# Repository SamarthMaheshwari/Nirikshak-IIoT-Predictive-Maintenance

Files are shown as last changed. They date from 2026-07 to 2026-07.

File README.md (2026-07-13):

# Nirikshak: Industrial IoT Predictive Maintenance System

<p align="center">
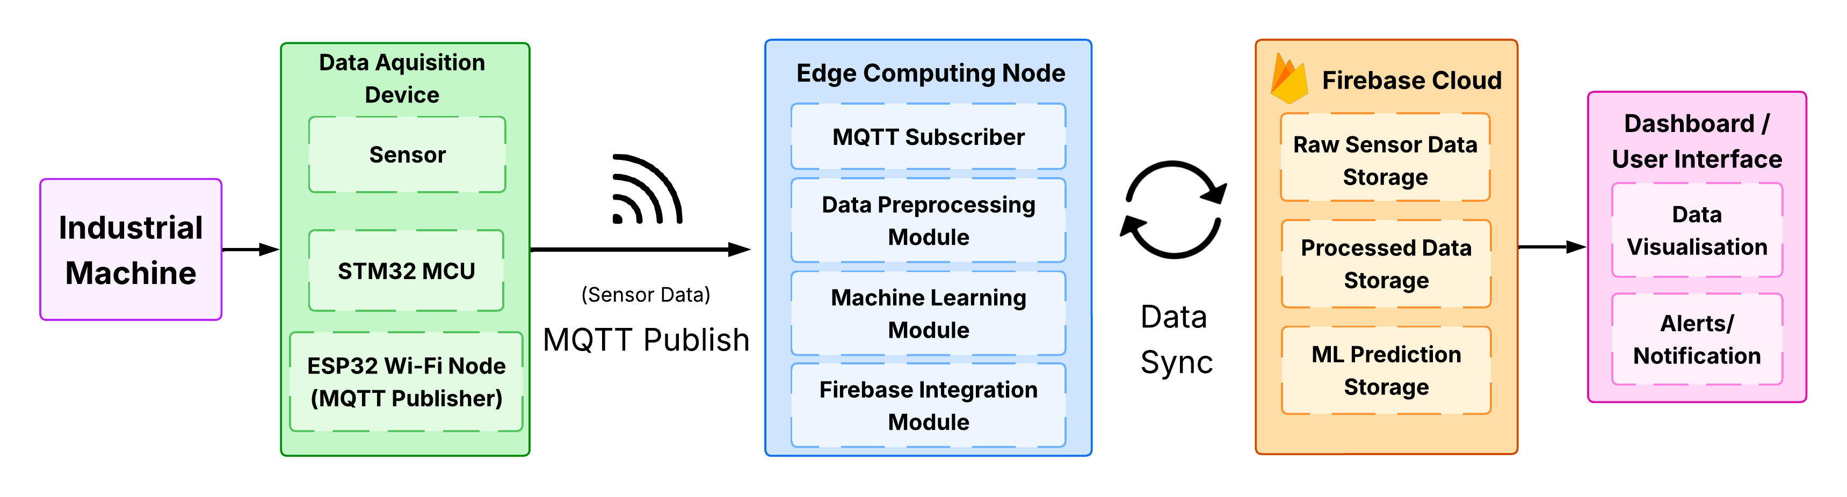
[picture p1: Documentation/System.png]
Nirikshak System
  
</p>

<p align="center">

An Industrial Internet of Things (IIoT) based Predictive Maintenance System for real-time monitoring of industrial motors using a custom STM32 Data Acquisition (DAQ) device, ESP32 wireless communication, and a web-based monitoring dashboard.

</p>

---

## Overview

Nirikshak is a low-cost Industrial IoT (IIoT) solution developed to continuously monitor the health of industrial motors.

The system collects data from multiple sensors using a custom-designed STM32-based DAQ device and wirelessly transmits it through an ESP32 module. The incoming telemetry is processed by a Python backend and visualized on a real-time dashboard, enabling continuous monitoring of machine operating conditions.

The project demonstrates the complete workflow of an embedded monitoring system—from hardware design and firmware development to wireless communication and web-based visualization.

---

# Features

- Real-time industrial motor monitoring
- Custom STM32-based Data Acquisition (DAQ) Device
- ESP32 wireless communication
- Multi-sensor data acquisition
- MQTT/Firebase based data transfer
- Live dashboard visualization
- Custom PCB designed in EasyEDA
- Custom 3D enclosure
- Modular firmware architecture
- Automatic dashboard fallback using simulated telemetry
- Easy-to-expand system architecture

---

# System Architecture

```
Industrial Motor
        │
        ▼
Sensors
│
├── MPU6050 (Vibration)
├── DS18B20 (Temperature)
├── ZMPT101B (Voltage)
├── SCT-013 (Current)
└── Inductive Proximity Sensor (RPM)
        │
        ▼
STM32 BlackPill
(Data Acquisition)
        │
UART
        │
        ▼
ESP32 DevKit V1
        │
Wi-Fi
        │
Firebase / MQTT
        │
Python Backend
        │
Real-Time Dashboard
```

---

# Hardware

## Microcontrollers

- STM32 BlackPill (STM32F411)
- ESP32 DevKit V1

## Sensors

- MPU6050
- DS18B20
- ZMPT101B Voltage Sensor
- SCT-013 Current Sensor
- Inductive Proximity Sensor

---

# Software Stack

| Software | Purpose |
|---|---|
| Arduino IDE | Firmware Development |
| Python | Backend & Dashboard |
| Flask | Web Dashboard |
| Socket.IO | Real-time Dashboard Updates |
| MQTT | Communication |
| Firebase | Cloud Data Storage |
| EasyEDA | PCB Design |
| Git & GitHub | Version Control |

---

# Repository Structure

```
Nirikshak
│
├── Firmware
│   ├── STM32
│   └── ESP32
│
├── Hardware
│   ├── PCB
│   └── 3D_Enclosure
│
├── Dashboard
│   ├── Backend
│   ├── Images
│   └── README.md
│
├── Documentation
│
├── Images
│
├── README.md
└── LICENSE
```

---

# Firmware

The firmware consists of two parts:

### STM32 Firmware

Responsible for:

- Sensor interfacing
- Data acquisition
- Signal processing
- UART communication

### ESP32 Firmware

Responsible for:

- Receiving data from STM32
- Wireless communication
- Sending telemetry to Firebase/MQTT

---

# Dashboard

The dashboard provides real-time visualization of sensor data including:

- Temperature
- Voltage
- Current
- RPM
- Vibration
- Machine Health Status
- Historical Readings
- System Statistics

The complete dashboard source code and setup instructions are available in:

```
Dashboard/README.md
```

---

# PCB

The custom DAQ PCB was designed using EasyEDA.

Included files:

- EasyEDA Project
- PCB Layout
- Schematic
- PCB Images
- 3D PCB View

---

# 3D Enclosure

The repository includes the custom enclosure designed for the DAQ device.

Contents include:

- STEP Files
- Preview Images

---

# Running the Project

## Firmware

Upload:

- STM32 firmware to the STM32 BlackPill
- ESP32 firmware to the ESP32 DevKit

---

## Dashboard

Navigate to the backend directory:

```bash
cd Dashboard/Backend
```

Install dependencies:

```bash
pip install -r requirements.txt
```

Run the dashboard:

```bash
python app.py
```

Open your browser and visit:

```
http://localhost:5000
```

For detailed dashboard instructions, see:

```
Dashboard/README.md
```

---

# Project Gallery

Add screenshots inside:

```
Images/
```

Example:

```
Images/
├── System.png
├── PCB.png
├── Dashboard.png
├── Enclosure.png
└── Hardware.jpg
```

---

# Future Improvements

- Industrial communication protocols (Modbus, CAN)
- OTA firmware updates
- Multi-machine monitoring
- Cloud deployment
- Mobile dashboard
- Edge-based predictive analytics

---

# Author

**Samarth Maheshwari**

Electronics & Telecommunication Engineering

**Areas of Interest**

- Embedded Systems
- Industrial IoT
- Firmware Development
- PCB Design

**GitHub**

https://github.com/SamarthMaheshwari

**LinkedIn**

https://www.linkedin.com/in/samarth-maheshwari-709670259

---
# Contributors

This project was developed as a collaborative Final Year Engineering Project.

- **Samarth Maheshwari**
- **Shriraj Dongare**
- **Anisha Pansare**

---

# Acknowledgements

This project was developed as a collaborative Final Year Engineering Project.

I would like to sincerely thank my teammates, **Shriraj Dongare** and **Anisha Pansare**, for their collaboration, dedication, and continuous support throughout the development of this project. Their teamwork and contributions were instrumental in successfully completing the project.

---

# License

This project is licensed under the MIT License.

See the LICENSE file for more information.

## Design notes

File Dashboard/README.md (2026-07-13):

# Dashboard

The Dashboard provides a real-time web interface for monitoring sensor data collected by the **Nirikshak Industrial IoT Predictive Maintenance System**.

It receives live sensor data through the backend, processes incoming telemetry, and displays the current machine status, historical data, and system statistics in an interactive web interface.

---

# Folder Structure

```
Dashboard/
│
├── Backend/
│   ├── app.py
│   ├── mqtt_subscriber.py
│   ├── config.py
│   ├── firebase_setup.py
│   ├── firebase_publisher.py
│   ├── pipeline.py
│   ├── requirements.txt
│   ├── templates/
│   ├── static/
│   ├── utils/
│   ├── ml/
│   ├── Firebase/
│   ├── Simulation/
│   └── Documentation/
│
├── Images/
└── README.md
```

---

# Features

- Real-time sensor monitoring
- Live dashboard updates using Socket.IO
- Historical data visualization
- Machine health monitoring
- Automatic fallback to simulated sensor data when no live data is available
- Responsive web interface

---

# Prerequisites

- Python 3.10 or later
- Internet connection (if using Firebase)
- Git (optional)

---

# Installation

Open a terminal inside the **Backend** folder.

Install the required Python packages:

```bash
pip install -r requirements.txt
```

---

# Running the Dashboard

Navigate to the Backend folder:

```bash
cd Dashboard/Backend
```

Run the application:

```bash
python app.py
```

If everything starts correctly, you should see a message similar to:

```
Nirikshak Dashboard -> http://localhost:5000
```

Open the displayed URL in your web browser.

Example:

```
http://localhost:5000
```

---

# Data Source

The dashboard automatically retrieves sensor data using the configured backend services.

Depending on the project configuration, data may come from:

- Firebase Realtime Database
- MQTT Subscriber
- Local simulator (automatic fallback)

If no live sensor data is available, the application generates simulated telemetry so the dashboard remains functional for demonstration purposes.

---

# Firebase Configuration

If you want to use your own Firebase project:

1. Create a Firebase Realtime Database.
2. Update the Firebase configuration in:

```
Backend/config.py
```

3. Replace the database URL with your own Firebase URL.

The Firebase folder also contains:

- Firebase security rules
- Firebase setup documentation

---

# Dashboard Pages

| Route | Description |
|---|---|
| `/` | Home page |
| `/home` | Home page |
| `/dashboard` | Real-time dashboard |
| `/api/latest` | Latest sensor data |
| `/api/history` | Historical data |
| `/api/stats` | System statistics |

---

# Notes

- `app.py` is the main entry point of the dashboard.
- The MQTT subscriber is started automatically in the background when the application launches.
- No additional terminal or manual execution of the subscriber is required.

---

# Screenshots

Add dashboard screenshots inside the `Images` folder and reference them here.

Example:

```
Images/
├── dashboard_home.png
├── dashboard_live.png
└── dashboard_statistics.png
```

---

# Troubleshooting

### Missing Python packages

Install all dependencies again:

```bash
pip install -r requirements.txt
```

---

### Dashboard does not open

Verify that:

- Python is installed correctly.
- All required packages are installed.
- The configured port is available.

---

### No live sensor data

The dashboard automatically switches to simulated sensor data when no live telemetry is detected, allowing the interface to remain operational for testing and demonstration.

---

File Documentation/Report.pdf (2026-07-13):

SAVITRIBAI PHULE PUNE UNIVERSITY

A PROJECT STAGE II REPORT
ON

## Nirikshak: An Industrial IoT & Predictive Maintenance Framework

SUBMITTED TOWARDS THE
PARTIAL FULFILLMENT OF THE REQUIREMENTS OF

### BACHELOR OF ENGINEERING

BY
Shriraj Dongare | Exam No: B401220134
Samarth Maheshwari | Exam No: B401220152
Anisha Pansare | Exam No: B401220159

### Under The Guidance of

Dr. Rupali Kawade

### DEPARTMENT OF ELECTRONICS AND TELECOMMUNICATION ENGINEERING

### Pimpri Chinchwad College of Engineering And Research Ravet

A.Y. 2025–2026

PCCOER, Department of E&TC Engineering 2025-26 | 1

### Pimpri Chinchwad College Of Engineering And Research DEPARTMENT OF ELECTRONICS AND TELECOMMUNICATION ENGINEERING

## CERTIFICATE

This is to certify that the Project Entitled

### Nirikshak: An Industrial IoT & Predictive Maintenance Framework

Submitted by

Shriraj Dongare | Exam No: B401220134
Samarth Maheshwari | Exam No: B401220152
Anisha Pansare | Exam No: B401220159

is a bonafide work carried out by Students under the supervision of Dr. Rupali Kawade and it is submitted towards the partial fulfillment of the requirement of Bachelor of Engineering (Electronics & Telecommunication Engineering) Project.

Dr. Rupali Kawade | Dr. K.M. Napte
Internal Guide | H.O.D
Dept. of E&TC Engg. | Dept. of E&TC Engg.
Dr. D.N. Dhake | Dr. H.U. Tiwari
Project Co-ordinator | Principal

EXTERNAL EXAMINER SIGNATURE

PCCOER, Department of E&TC Engineering 2025-26 | 2

Acknowledgement

It gives us great pleasure in presenting the Project Phase-II Report on “Nirikshak: An Industrial IOT & predictive Maintenance Framework”.

We would like to take this opportunity to thank our internal guide Dr. Rupali Kawade for giving us all the help and guidance needed. We are really grateful for the kind support and valuable suggestions provided throughout the project work. We would also like to thank our Project Coordinator Dr. D. N. Dhake for guidance and support.

We are also grateful to Dr. K. M. Napte, Head of the Department of Electronics and Telecommunication Engineering, PCCOER, Ravet, for indispensable support and valuable suggestions.

We are heartily thankful to Dr. H. U. Tiwari, Principal, PCCOER, Ravet, for providing all the support, guidance, research environment and constant motivation to improve our research profile

Shriraj Dongare
Samarth Maheshwari
Anisha Pansare
(B.E. E&TC Engineering)
Department of E&TC Engineering, PCCOER Ravet, 2025-26 | I

### Abstract

Predictive maintenance is an essential technology in Industry 4.0 for increasing equipment reliability, reducing unplanned downtime and minimizing maintenance costs. Conventional maintenance methods are not based on continuous condition monitoring and often lead to unnecessary maintenance or unexpected equipment failure. To tackle these challenges, this project proposes Nirikshak: An Industrial IoT & Predictive Maintenance Framework which provides a low cost and scalable solution for real-time machine health monitoring and intelligent fault prediction. The proposed framework uses a Data Acquisition (DAQ) device based on the STM32F103 integrated with temperature, vibration, RPM, voltage and current sensors to monitor continuously machine operating conditions. The collected sensor data is sent to an edge computing system via an ESP32 Wi-Fi module using the MQTT communication protocol. A Python-centric processing layer is employed for data preprocessing, feature extraction, anomaly detection, fault classification and Remaining Useful Life (RUL) estimation.
Machine learning techniques are used to provide predictive maintenance intelligence. We used Isolation Forest for the anomaly detection to detect abnormal machine behavior, Random Forest Classifier for the fault classification and Random Forest Regressor for Remaining Useful Life prediction . The processed sensor data and prediction results are synchronized with Firebase Realtime Database and visualized through a web-based dashboard that provides real time monitoring, machine health status, alerts, and historical trend analysis.
The developed framework was tested with machine condition data obtained under different operating conditions. Experimental results show effective anomaly detection, accurate fault classification, reliable RUL estimation, low communication latency and real-time responsiveness. The total hardware implementation cost is around Rs.8,500 which makes the system affordable and useful for small and medium scale industries. The proposed framework offers a feasible, scalable, and Industry 4.0-enabled solution for intelligent predictive maintenance applications.
Department of E&TC Engineering, PCCOER Ravet, 2025-26 | II

# INDEX

1 Introduction | 1
2 Literature Survey | 6
3 Methodology | 12
4 Design & Implementation of Proposed System | 15

5 Software Implementation | 31
6 Testing & Troubleshooting | 40
7 Advantages & Applications | 48
8 Conclusion & Future Scope | 51
9 References | 54
Annexure A Plagiarism Report | 56
Annexure B Copyright | 60
Annexure C Review Paper | 71
Annexure D Research Paper | 81
Department of E&TC Engineering, PCCOER Ravet, 2025-26 | IV

Annexure E Project Competition Participation | 91
Department of E&TC Engineering, PCCOER Ravet, 2025-26 | V

# List of Figures

3.1 Block Diagram | 13

4.1 System Architecture of Nirikshak Predictive Maintenance Framework 16
4.2 Flowchart of Nirikshak Predictive Maintenance Framework | 22
4.3 STM32F103 Development Board | 24
4.4 MPU6050 Vibration Sensor | 24
4.5 ESP32 Development Board | 25
4.6 DS18B20 Temperature Sensor | 25
4.7 Inductive Proximity Sensor (RPM Sensor) | 26
4.8 Voltage Sensor Module | 26
4.9 SCT-013 Current Sensor | 27
4.10 ST-Link Programmer | 27
4.11 Single Phase AC Motor | 28
4.12 DAQ Device Schematic | 30
4.13 DAQ Device PCB Layout | 30
5.1 Isolation Forest Anomaly Detection Results | 35
5.2 Random Forest Fault Classification Confusion Matrix | 36
5.3 Actual vs Predicted Remaining Useful Life | 37
6.1 Temperature Trend Analysis | 43
6.2 Vibration Trend Analysis | 43
6.3 RPM Trend Analysis | 44
6.4 Current Trend Analysis | 44
6.5 Voltage Trend Analysis | 44
6.6 Real-Time Monitoring Dashboard | 45
6.7 Real-Time Monitoring Dashboard | 45

# List of Tables

# CHAPTER 1 INTRODUCTION

## 1.1 Overview

The rapid adoption of Industry 4.0 has developed intelligent maintenance solutions capable of improving equipment reliability and reducing operational downtime. Predictive Maintenance (PdM) has emerged as an effective maintenance strategy that utilizes real-time machine condition data and advanced analytics for ear;ier fault detection. Unlike conventional reactive and preventive maintenance approaches, predictive maintenance enables condition-based decision-making, thereby reducing maintenance costs and improving asset utilization.
The proposed project, Nirikshak: An Industrial IoT-Based Predictive Maintenance Framework, integrates embedded systems, Industrial Internet of Things (IIoT), edge computing, cloud computing, and machine learning into a unified monitoring platform. The system employs an STM32-based Data Acquisition (DAQ) unit interfaced with temperature, vibration, RPM, voltage, and current sensors to continuously monitor machine health parameters. The collected data is transmitted using the MQTT protocol and processed at an edge computing node for feature extraction and analysis. The collected sensor information is analyzed using intelligent prediction models that identify equipment faults, detect abnormal behavior, and estimate the remaining operational lifespan of machinery. Firebase Realtime Database act as a cloud based platform for data storage and synchronization, while a web-based dashboard provides real-time visualization of machine conditions, alerts, and predictive insights. The framework offers a low-cost, scalable, and practical solution for modern industrial maintenance applications.

## 1.2 Need and Relevance

Industrial equipment failures often result in unplanned downtime, production losses, increased maintenance expenses, and reduced operational efficiency. Traditional maintenance strategies either react after a failure occurs or follow fixed maintenance schedules without considering the actual condition of the machine. Such approaches can lead to inefficient resource utilization and unexpected breakdowns.
The growing adoption of Industry 4.0 technologies identifies the need for intelligent maintenance systems capable of continuous monitoring and predictive analysis. An Industrial IoT-based predictive maintenance helps to detect faults early through real-time sensor data and machine learning techniques.Small and medium-sized industries mostly used this proposed system, by combining low-cost hardware, cloud connectivity, and advanced analytics to improve machine reliability and maintenance planning.
Department of E&TC Engineering, PCCOER Ravet, 2025-26 | 2

## 1.3 Motivation

Modern industries increasingly rely on uninterrupted machine operation to maintain productivity and competitiveness. Mostly,predictive maintenance solutions are expensive, proprietary, and difficult to customize for specific industrial requirements. These limitations restrict their adoption, especially among small and medium enterprises.
The motivation behind this project is to develop an accessible and cost-effective predictive maintenance framework that combines Industrial IoT technologies with machine learning-based intelligence. By integrating real-time sensing, edge computing, cloud storage, and predictive analytics, the system provides actionable insights into machine health conditions. The ability to detect anomalies, predict faults, and estimate Remaining Useful Life can help industries minimize downtime, reduce maintenance costs, and improve operational safety. Furthermore, the project demonstrates the practical implementation of Industry 4.0 concepts using open-source technologies and low-cost embedded hardware.

## 1.4 Problem Statement

To develop a low-cost, customizable Industrial IoT system that collects real-time machine data, predicts failures using machine learning, and displays key parameters through a user-friendly dashboard for efficient predictive maintenance.

## 1.5 Aim and Objectives

Industrial IoT-based predictive maintenance framework is capable of real-time machine monitoring, fault prediction, anomaly detection, and Remaining Useful Life estimation using embedded sensing, edge computing, cloud integration, and machine learning techniques
Objectives:
- To make the DAQ (Data Acquisition) device efficiently collect sensor data in real time.
- Real time transmission of collected data to a cloud platform running on a processing device.
- To implement proper data processing and machine learning techniques for predicting potential failures.

- To develop a custom dashboard that easily interprets data and sends notifications and alerts for timely action.
- To estimate machine health status and Remaining Useful Life (RUL) using predictive analytics techniques.

## 1.6 Project Scope and Limitations

The proposed framework focuses on real-time monitoring and predictive maintenance of industrial machines such as motors, pumps, compressors, and other rotating equipment. The system supports multi-sensor data acquisition, MQTT-based communication, edge-level data processing, cloud synchronization through Firebase, machine learning-based fault prediction, anomaly detection, and RUL estimation. The modular architecture allows future scalability through the addition of new sensors, machines, and predictive models.
However, the system is developed and validated in a controlled experimental environment using a limited set of machine operating conditions and sensor configurations. The accuracy of fault prediction depends on available training data. Large-scale industrial deployment may require additional cybersecurity measures, model retraining mechanisms, and integration with existing industrial automation infrastructure. Furthermore, environmental variations and unforeseen machine faults may affect prediction performance.

## 1.7 Organisation of the Report

The project report is organized as follows:
Chapter 1 introduces the Nirikshak framework as a solution and describes the overview, need and relevance, motivation, problem statement, objective, scope and limitation of the project.
Chapter 2 covers literature survey on Industrial IoT, predictive maintenance, machine learning, edge computing and other relevant researches.
Chapter 3 describes the proposed methodology, project framework, data acquisition process, communication architecture, and overall system workflow.
Chapter 4 explains the design workflow and implementation of the proposed system, including the system architecture, flowchart, hardware components, sensor interfacing, and PCB development.
Chapter 5 discusses the software implementation of the framework, covering MQTT communication, data preprocessing, machine learning models, cloud integration, and dashboard visualization.

Chapter 6 presents the testing methodology, troubleshooting procedures, testing results, and performance analysis of the developed system.
Chapter 7 highlights the advantages and industrial applications of the proposed predictive maintenance framework.
Chapter 8 concludes the report by summarizing the major outcomes of the project and discusses the future scope improvements and large-scale deployment.

# CHAPTER 2 LITERATURE SURVEY

## 2.1 Literature Survey

Predictive maintenance is one of the prominent technologies of Industry 4.0 for which various research papers, journals, conference papers, and industrial papers on IIoT, machine condition monitoring, anomaly detection, fault diagnosis and RUL prediction have been surveyed.The surveyed literature demonstrates how the combination of IoT devices, cloud computing, edge computing, artificial intelligence, and machine learning algorithms is used to design intelligent predictive maintenance systems. This review discusses some of the important contributions made by the recent research work related to the proposed Nirikshak: An Industrial IoT Predictive Maintenance Framework. The papers selected for this survey were identified from references and related papers of the project research work..

1. Theissler et al. (2021) [1], in their paper ”Machine Learning Techniques for Predictive Maintenance in the Auto- motive Industry” published in Reliability Engineering System Safety was an in-depth review of the use of machine learning techniques in predicting maintenance needs in industry. This article covered the use of machine learning techniques in condition monitoring, failure diagnos- is and maintenance planning based on data. Machine learning techniques, sensor technology, and industrial data analytics were applied. The results proved that machine learning can increase the accuracy of failure prediction and enhance maintenance efficiency. Nevertheless, issues like data quality and deployment were encountered.
2. Samatas et al. (2021) [2], in their paper “Predictive Maintenance: Bridging Artificial Intelligence and IoT” presented at the IEEE World AI IoT Congress (AIIoT), proposed an integrated framework combining Artificial Intelligence and Internet of Things technologies for predictive maintenance applications. The study focused on continuous equipment monitoring through connected sensors and intelligent analytics. The work utilized IoT communication systems, cloud computing platforms, and AI-based prediction models. The results demonstrated improved decision-making capabilities and proactive maintenance scheduling. The proposed approach contributed to reducing unexpected equipment failures and operational downtime.
3. Tasci et al. (2023)[3] in their paper “Remaining Useful Lifetime Prediction for Predictive Maintenance in Manufacturing” published in Computers & Industrial Engineering, developed a framework for estimating Remaining Useful Life (RUL) of industrial equipment. The research focused on prognostics and health management using historical and real-time machine data. Technologies such as time-series analysis, machine learning algorithms, and predictive analytics were employed. The study demonstrated that accurate RUL prediction enables optimized maintenance planning and better resource utilization. The system improved operational reliability by providing early warnings before equipment failure.
4. Savaglio et al. (2024) [4] in their paper “Edge Intelligence for Industrial IoT: Opportunities and Limitations” published in Procedia Computer Science, discussed the role of edge computing in Industrial IoT applications. The study explored how intelligence can be deployed closer to industrial machines for faster decision-making and reduced network latency. Technologies including edge computing, Industrial IoT platforms, distributed analytics, and machine learning were investigated. The findings demonstrated that edge intelligence improves real-time responsiveness and bandwidth efficiency. However, limitations related to computational resources and security challenges were also highlighted.
5. Elkateb et al. (2024) [5], in their paper “Machine Learning and IoT-Based Predictive Maintenance Approach for Industrial Applications” published in the Alexandria Engineering Journal, proposed an intelligent predictive maintenance system using IoT-enabled sensors and machine learning models. The work focused on monitoring equipment health and detecting abnormal operating conditions at an early stage. Technologies such as IoT sensors, cloud computing, supervised learning algorithms, and data analytics were utilized. The results demonstrated improved fault detection performance and enhanced maintenance efficiency. The study emphasized the importance of integrating machine learning with real-time industrial monitoring systems.
6. Cummins et al. (2024)[6] in their paper “Explainable Predictive Maintenance: A Survey of Current Methods, Challenges and Opportunities” published in IEEE Access, reviewed explainable artificial intelligence techniques used in predictive maintenance applications. The study focused on improving transparency and trust in machine learning-based maintenance systems. Technologies including Explainable AI (XAI), deep learning, predictive analytics, and industrial monitoring systems were analyzed. The findings demonstrated that explainable models improve user confidence and facilitate maintenance decision-making. The paper also identified challenges associated with balancing model accuracy and interpretability.

7. Andriulo et al. (2024)[7] in their paper “Edge Computing and Cloud Computing for Internet of Things: A Review” published in Informatics, presented a detailed review of edge-cloud architectures for IoT applications. The research focused on efficient data processing, storage, and communication mechanisms for large-scale IoT systems. Technologies such as cloud computing, edge computing, IoT frameworks, and distributed systems were examined. The study showed that combining edge and cloud platforms improves scalability, reliability, and real-time processing capabilities. The proposed concepts are highly relevant for industrial predictive maintenance deployments.
8. Artiushenko et al. (2024)[8] in their paper “Resource-Efficient Edge AI Solution for Predictive Maintenance” published in Procedia Computer Science, proposed a lightweight Edge AI framework for industrial predictive maintenance. The study focused on deploying machine learning models directly on resource-constrained edge devices. Technologies such as Edge AI, embedded systems, sensor networks, and optimized machine learning algorithms were employed. The results demonstrated reduced latency and efficient fault detection without excessive cloud dependency. The framework highlighted the feasibility of low-cost intelligent maintenance systems for industrial applications.
9. Hamasha et al. (2025)[9] in their paper “A Comprehensive Framework for IoT-Driven Predictive Maintenance: Leveraging AI and Edge Computing for Enhanced Equipment Reliability” published in the Journal of Applied Engineering Science, proposed a complete predictive maintenance architecture integrating IoT, Artificial Intelligence, and edge computing. The work focused on improving equipment reliability through continuous monitoring and intelligent analytics. Technologies including IoT sensors, edge devices, machine learning models, and cloud infrastructure were utilized. The findings demonstrated significant improvements in fault prediction accuracy and maintenance efficiency. The framework provided a scalable solution suitable for Industry 4.0 environments
10. Rakholia et al. (2025) [10] in their paper “Integrating AI and IoT for Predictive Maintenance in Industry 4.0 Manufacturing Environments: A Practical Approach” published in Information, presented a practical implementation of AIenabled predictive maintenance for smart manufacturing systems. The study focused on real-time machine monitoring, anomaly detection, and predictive analytics. Technologies such as Industrial IoT, machine learning, cloud computing, and intelligent sensors were employed. The proposed approach improved equipment availability and reduced maintenance costs through proactive fault management. The study demonstrated the effectiveness of combining AI and IoT technologies for industrial applications.

## 2.2 Research Gap

It can be concluded from the literature review that the application of predictive maintenance with Industrial IoT has become an interesting field of research because of using machine learning, edge computing, and cloud computing technologies. The majority of the studies prove that machine learning has already been used successfully in fault detection, anomaly detection, and condition monitoring. However, there is an evident shortage of comprehensive and practical solutions in the area of predictive maintenance. In most cases, existing solutions cover only separate elements of the process.
Most of the developed approaches are based on the cloud processing, which is likely to cause higher latencies and non-real time processing problems. Also, some of the studies consider only the prediction algorithms without combining multi-sensor data collection, communication, edge computing, cloud storage and visualization. In addition, some of the industrial predictive maintenance solutions need expensive software and hardware infrastructure to implement the solution.
Thus, such solutions are less applicable for small and medium-sized enterprises.Other limitation that exists in the literature is absence of low-cost systems which integrate fault classification, anomaly detection and RUL prediction. In addition to that there is an absence of real-life deployment implementations that use affordable hardware with real time monitoring capabilities. To solve the above stated limitations, the proposed NIRIKSHAK: An Industrial IoT Pre-dictive Maintenance Framework brings together multiple sensor monitoring, MQTT based communication, edge and cloud computing along with machine learning approaches in one single architecture. The system makes use of Random Forest Classifier for fault classification, Isolation Forest for anomaly detection and Random Forest Regressor for RUL prediction.

### 2.2.1 Research Gaps Identified

The following research gaps were identified from the literature survey:
- Lack of complete end-to-end IIoT-based predictive maintenance frameworks.
- Limited integration of fault classification, anomaly detection, and Remaining Useful Life (RUL) estimation within a single framework.

- Heavy dependence on cloud-based processing, resulting in increased latency and reduced real-time responsiveness.
- High implementation cost of existing solutions, making them difficult for Small and Medium-sized Enterprises (SMEs) to adopt.
- Limited utilization of edge computing for real-time data processing and analytics.
- Lack of affordable, scalable, and practically deployable industrial predictive maintenance systems.
- Insufficient integration of real-time monitoring dashboards with predictive maintenance models for effective decision-making.

## 2.3 Summary

In Industrial 4.0 settings, predictive maintenance is evident through an extensive body of literature. Studies have shown how Industrial IoT, machine-learning algorithms, edge computing, cloud platforms, anomaly detection, and RUL predictions improve machine reliability and decrease downtime. As such, these findings inspired the creation of the Nirikshak framework; a complete predictive maintenance solution that leverages real-time monitoring, MQTT communication, cloud connectivity, and machine-learning predictive analytics into one cohesive system.

# CHAPTER 3 METHODOLOGY

## 3.1 Project Framework

Nirikshak: An Industrial Iot & Predictive Maintenance Framework will be designed to monitor the condition of industrial machines and predict possible failure beforehand. The proposed framework combines IIoT, embedded systems, machine learning, cloud storage, and visualization to offer an intelligent maintenance solution. The system utilizes an edge-cloud computing architecture wherein condition parameters of the machine including temperature, vibrations, voltage, current, and revolutions per minute are obtained through various sensors and DAQ system, namely STM32. The data obtained are then sent wirelessly using an ESP32 communication module and MQTT protocol to an edge computing system.
In terms of edge computing, machine learning algorithms are used for analyzing and processing the data for detecting faults, identifying anomalies, determining the machine’s health condition, and scheduling preventive maintenance tasks. The processed data and the prediction results are synced with the Firebase Real-time Database and visualized via the web interface.

## 3.2 Block Diagram

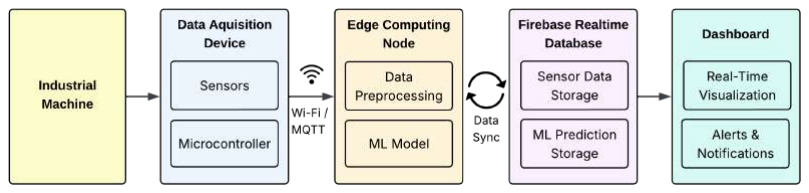
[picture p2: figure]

Figure 3.1: Block Diagram

### 3.2.1 Components Of Block Diagram:

1. Industrial Machine
The industrial machinery means the machines being observed through the process of predictive maintenance. Machines like motors, pumps, compressors, and rotating machines generate various operational data such as temperature, vibrations, voltage, current, and speed. Continuous observation of such parameters allows us to evaluate the health status of the machines and detect any anomalies.
2. Data Acquisition Device

The Data Acquisition Module is made up of sensors which are connected to the STM32F103 microcontroller and ESP32 wireless module. These sensors continually collect data concerning the performance of the machine including its temperature, vibrations, voltage, current, and RPM.
- DS18B20 Temperature Sensor – Measures machine temperature.
- MPU6050 Sensor – Monitors vibration characteristics.
- Inductive Proximity Sensor – Measures shaft rotational speed (RPM).
- ZMPT101B Voltage Sensor – Measures supply voltage.
- SCT-013 Current Sensor – Measures current consumption.
STM32F103 microcontroller is responsible for data collection, ADC conversion, data validation, and packaging the collected data for transmission. The ESP32 wireless module acts as a Wi-Fi communication node and transfers the collected sensor data to the edge computing node through the MQTT protocol.
3. Edge Computing Node
Data is obtained in real-time through MQTT and processed locally at the Edge Computing Node. Preprocessing includes activities such as data cleaning, normalization, and extraction of features.
Machine learning techniques are applied to determine the machine’s condition, detect any deviations or anomalies, classify any faults that arise, and estimate potential future degradations.
4. Firebase Realtime Database
The Firebase Realtime Database is the cloud-based storage solution for the system. This database contains sensor readings, ML predictions, anomaly detection data, and logs. The database allows for centralization of data management and enables remote access to the data.
5. Dashboard and Visualization Layer
Dashboard provides the operator with an intuitive interface for monitoring equipment in real time. It pulls data from Firebase Realtime Database to display live readings from sensors, the condition of the equipment, prediction results, trends in data and maintenance alerts. Dashboard helps the operator to make well-informed maintenance decisions to minimize the frequency of equipment breakdowns.

# CHAPTER 4 DESIGN & IMPLEMENTATION OF PROPOSED SYSTEM

## 4.1 System Overview

The proposed Nirikshak: An Industrial IoT & Predictive Maintenance Framework is continuous monitoring of machine condition, anomalies detection, faults diagnosing, and Remaining Useful Life (RUL) prediction for industrial devices.An effective predictive maintenance solution is formed by combining IIoT, embedded systems, edge computing, machine learning, cloud storage, and real-time visualization. Continuous monitoring of machine state and early detecting of anomalies become the primary goal of the proposed framework, which is achieved in order to prevent machine failure. Traditional approaches often lead to unnecessary downtimes and high maintenance costs. In order to eliminate such disadvantages, the framework allows performing condition-based maintenance thanks to continuous data collecting and analysis.
Machine health indicators, which include temperature, vibration, RPM, voltage, and current, are collected from several types of sensors.Data Acquisition Deviceis used for data collection based on STM32F103 and transmitted via Wi-Fi module (ESP32). At the edge computing level, machine learning algorithms perform fault classification, anomalies detection, and RUL prediction. All results are synchronized with Firebase Realtime Database and visualized in the form of web dashboard.

## 4.2 System Architecture

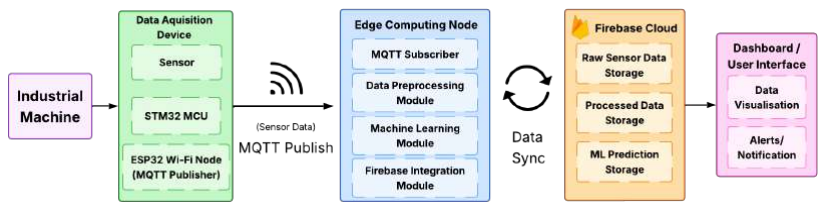
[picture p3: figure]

Figure 4.1: System Architecture of Nirikshak Predictive Maintenance Framework Nirikshak architecture is designed to leverage a tiered structure of IIoT technology architecture, which contain data acquisition layer, communication layer, edge processing layer, cloud storage layer, and visualization layer. This architecture facilitates continuous monitoring of machine state and allows predictive maintenance analysis.

1. Industrial Machine
In the case of industrial machinery, the monitored equipment includes induction motors, pumps, compressors, generators, and rotational equipment. When the machinery is operating, it generates physical and electrical variables indicating its condition. Any change in the generated variables shows any kind of deterioration or malfunctioning in the machinery.
2. Data Acquisition Device
The Data Acquisition Device acts as the hardware interface connecting the industrial machines to the predictive maintenance system. It continuously acquires machine condition parameters and packages them for transferring them to the edge computing node. The data acquisition device includes sensing modules, microcontroller unit, and wireless communication interface to ensure reliable data acquisition and communication.
- Sensors A number of sensors are used to collect the required indicators of machine health. The DS18B20 temperature sensor acquires changes in the machine’s temperature to assist in determining when the machine may be developing overheating issues. The MPU6050 sensor collects vibrations that are helpful in identifying imbalance, misalignment, bearing failure, and mechanical deterioration. An inductive proximity sensor collects the revolutions per minute (RPM) of the machine’s shaft. Electrical indicators are acquired through the use of ZMPT101B voltage sensor and SCT-013 current sensor to determine power consumption levels. In summary, these sensors collectively gives all information about the machine’s operating conditions.
- STM32F103 Microcontroller The STM32F103 microcontroller acts as the master controller of the data acquisition device. All sensor modules are connected to the microcontroller and machine condition parameter acquisition occurs locally. The microcontroller performs real-time sensor readings, analog-to-digital conversions, calibration processes, validation of acquired data, and structuring the sensor readings into a proper format. This way, the STM32 ensures that only reliable information is transferred to the communication node.
- ESP32 Wi-Fi Node The ESP32 module works as the communication interface in the framework. Machine condition data acquired through the STM32 are sent wirelessly through Wi-Fi connectivity. The ESP32 pushes the collected machine condition data to MQTT topics and controls network communication between the data acquisition node and edge computing node. The networking capabilities of the module simplify framework implementation while providing reliable data transfer. Reconnection procedures and communication management are handled by the ESP32 module.

3. Edge Computing Node
The Edge Computing Node represents the main processing layer of the framework and implements all machine learning procedures locally. The processing layer gets machine condition data from the communication network, preprocesses the acquired information, analyzes and predicts the occurrence of possible failures, and produces maintenance intelligence.
- MQTT Subscriber The MQTT Subscriber is connected to the MQTT broker and continuously receives real-time sensor data published by the ESP32 communication node. it subscribes to topics, consumes incoming data streams and stores received data for later analysis. The subscriber is the entry point to the edge computing layer, which guarantees reliable collection of machine condition data. Received measurements are stored and then forwarded to subsequent processing modules for predictive maintenance analysis.
- Data Preprocessing Module Sensor data is pre-processed prior to machine learning analysis to improve data quality and model performance. This phase extracts useful features from the incoming sensor packets, removes incomplete or invalid records, normalizes feature values, reduces noise, and parses the sensor packets. Proper preprocessing ensures consistency across datasets and allows machine learning models to make more accurate predictions. The processed data will be used as input for algorithms of predictive maintenance.
- Machine Learning Module Machine Learning Module is the smart component of the architecture. This module analyzes the processed data coming from the sensors in order to determine the status of the machine, as well as its future operating conditions. The engine is capable of diagnosing machine problems using fault classification techniques, detecting abnormal machine behavior via anomaly detection methods, and predicting the life span of the machine prior to failure using remaining useful life estimation techniques. Machine learning module takes the raw sensor data and transforms it into maintenance-related information.
- Firebase Integration Module The Firebase Integration Module is responsible for synchronizing processed sensor data and machine learning results with the cloud platform. After analysis is completed, the module formats prediction outputs, updates database records, uploads machine health information, and stores anomaly detection results. This module ensures seamless communication between the edge computing environment and the cloud infrastructure, enabling remote accessibility and centralized data management.

4. Firebase Cloud Platform Firebase Realtime Database is the centralized cloud storage platform of the framework. Raw sensor measurements, processed data, machine learning predictions, anomaly information and historical operational records are stored. The cloud platform allows real-time synchronization between multiple system components and secure remote access to machine condition information. Historical records stored in the database support long-term trend analysis, maintenance planning and performance evaluation.
5. Dashboard/User Interface The Dashboard offers real-time visualization and monitoring for machine operators and maintenance personnel. The web-based interface pulls data from Firebase Realtime Database and displays machine condition data using interactive charts, indicators and status panels. They can be used for real-time sensor data monitoring, machine health states, fault prognostics, anomaly detection, historical performance trends and Remaining Useful Life. The dashboard enables maintenance teams to make informed decisions based on real-time operational insights and helps support proactive maintenance planning to improve equipment reliability and reduce operational expenses.

## 4.3 Flow Chart

The operation of the proposed Nirikshak framework follows a systematic sequence of steps for real-time machine condition monitoring and predictive maintenance, as illustrated in Figure 4.2.

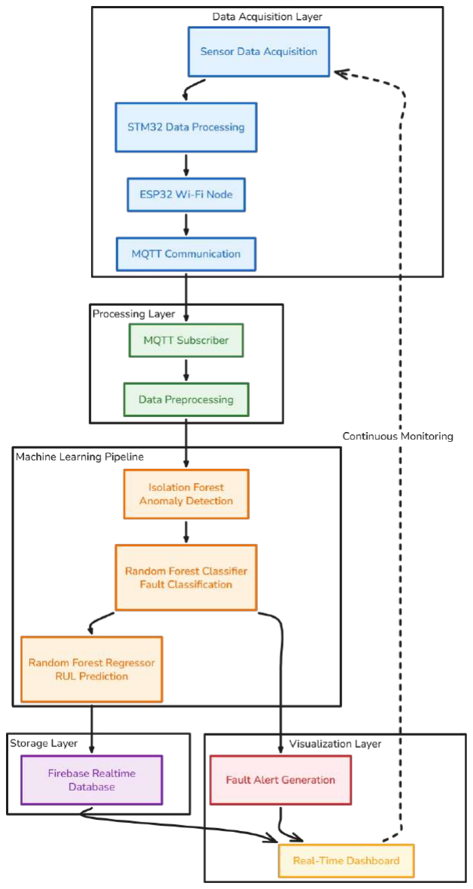
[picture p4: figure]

Figure 4.2: Flowchart of Nirikshak Predictive Maintenance Framework

1. The system continuously acquires machine health parameters such as temperature, vibration, current, voltage, and rotational speed (RPM) using multiple industrial sensors connected to the data acquisition unit.
2. The acquired sensor readings are processed by the STM32F103 microcontroller, where sensor interfacing, analog-to-digital conversion, data filtering, and formatting operations are performed.
3. The processed data is transmitted to the ESP32 Wi-Fi module through UART communication. The ESP32 acts as the communication interface between the embedded hardware and the monitoring system.
4. The ESP32 publishes the sensor readings to the MQTT broker, enabling reliable real-time wireless communication between the data acquisition device and the edge computing node.
5. A Python-based MQTT subscriber receives the incoming sensor data and performs data ingestion and preprocessing operations, including data validation, formatting, normalization, and preparation for machine learning analysis.
6. The preprocessed data is first analyzed using the Isolation Forest anomaly detection model to identify abnormal operating conditions and generate an anomaly score indicating the likelihood of abnormal machine behavior.
7. The processed data is then supplied to the Random Forest Classifier, which identifies the machine’s operating condition and classifies potential fault types such as bearing faults, overheating conditions, or electrical abnormalities.
8. Subsequently, the Random Forest Regressor estimates the Remaining Useful Life (RUL) of the machine, providing an indication of the expected operational duration before maintenance or replacement is required.
9. The generated anomaly status, fault classification results, and RUL predictions are stored in the Firebase Realtime Database. If a fault condition is detected, the system generates an alert notification for maintenance personnel.
10. The dashboard retrieves real-time sensor data and prediction results from Firebase and displays machine health information, fault alerts, anomaly status, and predictive maintenance insights.
11. The monitoring process continues continuously, enabling real-time machine condition assessment and predictive maintenance decision support.

## 4.4 Electronic Components Used

The Nirikshak framework consists of sensors, microcontrollers, communication modules, and power supply units that work together to monitor machine health in real time. These components enable reliable data acquisition, processing, and transmission for predictive maintenance applications.

1. STM32F103 Development Board

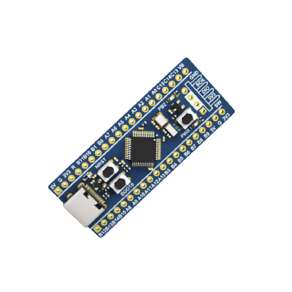
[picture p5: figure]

Figure 4.3: STM32F103 Development Board

STM32F103C8T6 is a 32-bit ARM Cortex-M3 microcontroller operating at 72 MHz. It acts as the main controller of the system by acquiring sensor data, processing it, and transmitting it to the communication module for further analysis.

2. MPU6050 Vibration Sensor

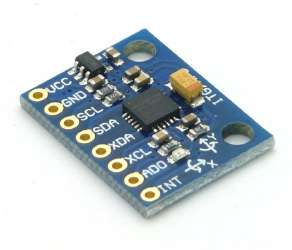
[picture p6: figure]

Figure 4.4: MPU6050 Vibration Sensor

MPU6050 is a six-axis MEMS sensor that combines a three-axis accelerometer and a three-axis gyroscope. It is used to measure machine vibration and motion, enabling continuous condition monitoring and fault detection.

3. ESP32 WiFi Node

Figure 4.5: ESP32 Development Board

The ESP32 is a Wi-Fi and Bluetooth-enabled microcontroller used as the communication interface in the proposed framework. It receives sensor data from the STM32F103 via UART and transmits it wirelessly using the MQTT protocol. Its networking capabilities enable real-time data transfer, remote monitoring, and Industrial IoT connectivity between the data acquisition unit and the edge computing node.

4. DS18B20 Temperature Sensor

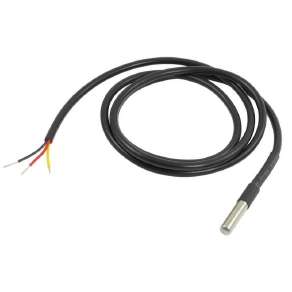
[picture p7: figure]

Figure 4.6: DS18B20 Temperature Sensor

DS18B20 is a digital temperature sensor with one-wire communication capability. The sensor converts temperature into digital data and transmits it directly to the microcontroller. It is used to monitor machine temperature and identify overheating conditions that may affect equipment performance and reliability.

5. Inductive Proximity Sensor (RPM Sensor)

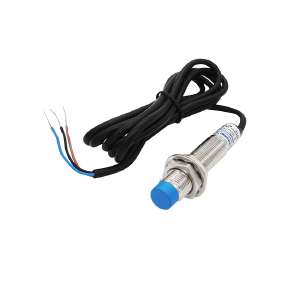
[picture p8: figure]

Figure 4.7: Inductive Proximity Sensor (RPM Sensor)

An inductive proximity sensor detects metallic objects without physical contact. It generates pulses whenever a rotating metallic object passes near the sensing surface. The sensor is used for rotational speed (RPM) measurement by counting the generated pulses and determining the speed of rotating machinery.

6. Voltage Sensor Module (ZMPT101B)

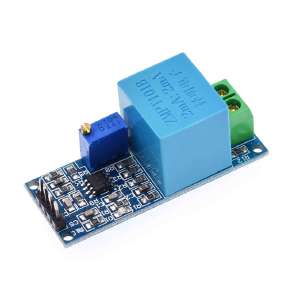
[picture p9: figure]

Figure 4.8: Voltage Sensor Module

The ZMPT101B voltage sensor module measures AC voltage supplied to industrial equipment. The input voltage is scaled down to a safe range suitable for microcontroller ADC inputs. It is used for voltage monitoring and power quality assessment by continuously measuring supply voltage and detecting abnormal voltage conditions.

7. SCT-013 Current Sensor

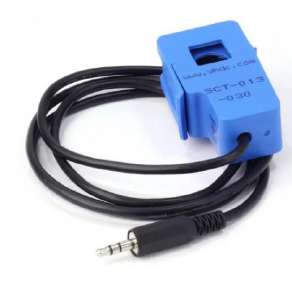
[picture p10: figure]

Figure 4.9: SCT-013 Current Sensor

SCT-013 is a non-invasive current transformer sensor designed to measure alternating current without direct electrical contact. The sensor generates a proportional output signal corresponding to the current flowing through the conductor. It is used for monitoring machine current consumption and helps in assessing equipment load conditions and electrical performance.

8. ST-Link Programmer

Figure 4.10: ST-Link Programmer

ST-Link is a programming and debugging tool designed for STM32 microcontrollers. It communicates with the microcontroller through the Serial Wire Debug (SWD) interface and uploads firmware to the target device. The tool is used for program development, debugging, testing, and firmware updates, enabling efficient software deployment and troubleshooting during system development.

9. Experimental Test Motor

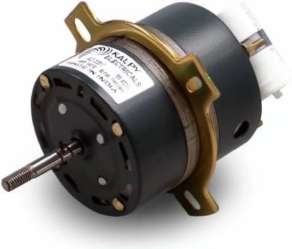
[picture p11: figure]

Figure 4.11: Single Phase AC Motor

A single-phase AC fan motor was used as the test machine for demonstrating the proposed predictive maintenance framework. The motor serves as the industrial equipment under monitoring and provides real-time operating parameters such as temperature, vibration, current consumption, supply voltage, and rotational speed (RPM). These parameters are continuously acquired through the data acquisition system and analyzed using machine learning algorithms to assess machine health and predict potential faults.
The selected motor is a high-speed all-purpose fan motor rated at 230 VAC and 100 W. The motor is equipped with a 4 µF capacitor for starting and running operation. Due to its continuous rotational operation and ease of experimentation, it provides a suitable platform for validating the proposed Industrial IoT-based predictive maintenance framework.
Table 4.1: Experimental Test Motor Specifications
Parameter | Specification
Motor Type | Single-Phase AC Fan Motor
Rated Voltage | 230 VAC
Rated Power | 100 W
Supply Frequency | 50 Hz
Capacitor Rating | 4 µF, 450 VAC
Mounting Type | Flange Mount
Cooling Method | Self-Air Cooled
Application | Predictive Maintenance Demonstration

## 4.5 PCB Design and Development

A custom Printed Circuit Board (PCB) was designed to integrate the STM32F103 microcontroller, ESP32 communication module, sensor interfaces, power supply circuitry, and signal conditioning components into a single compact hardware platform. The PCB serves as the Data Acquisition (DAQ) device of the Nirikshak framework and simplifies sensor interfacing while improving system reliability and maintainability.

### 4.5.1 PCB Schematic Design

The schematic was developed using EasyEDA based on the hardware requirements of the predictive maintenance framework. The STM32F103 Black Pill microcontroller acts as the central controller and interfaces with all sensing modules. The ESP32 module provides wireless communication through the MQTT protocol. Dedicated interfaces were incorporated for vibration, temperature, voltage, current, and RPM sensors.
The schematic also includes:
- STM32F103 Black Pill microcontroller
- ESP32 DevKit communication module
- DS18B20 temperature sensor interface
- MPU6050 vibration sensor interface
- ZMPT101B voltage sensor interface
- SCT-013 current sensor conditioning circuit
- Inductive proximity sensor interface for RPM measurement
- Power supply and switching circuitry

### 4.5.2 PCB Layout Design

After schematic verification, the PCB layout was generated in EasyEDA. Component placement was optimized to minimize routing complexity and facilitate sensor connectivity. The STM32F103 controller was positioned at the center of the board, while sensor connectors and power interfaces were placed along the edges for easy access. Separate routing paths were maintained for sensor signals, power distribution, and communication lines to improve overall system organization.
The final PCB layout integrates all required subsystems into a compact DAQ device suitable for industrial monitoring applications.

### 4.5.3 Advantages of the Custom PCB

The developed PCB provides several advantages:
- Compact integration of all hardware components
- Reduced wiring complexity
- Improved reliability and maintainability
- Easy sensor interfacing and replacement
- Simplified deployment in industrial environments
- Dedicated communication and power management circuitry

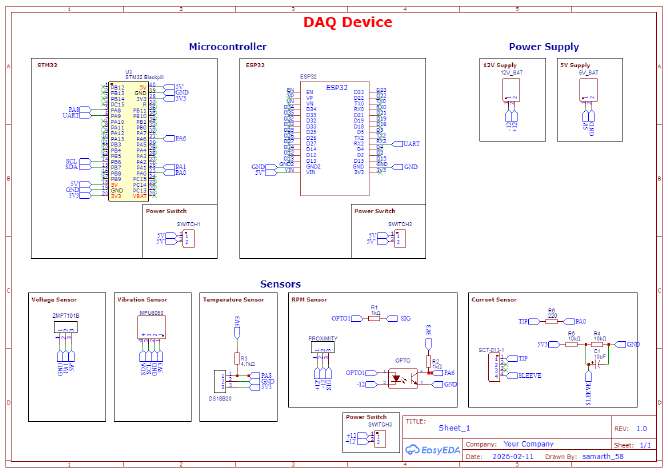
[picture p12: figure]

Figure 4.12: DAQ Device Schematic

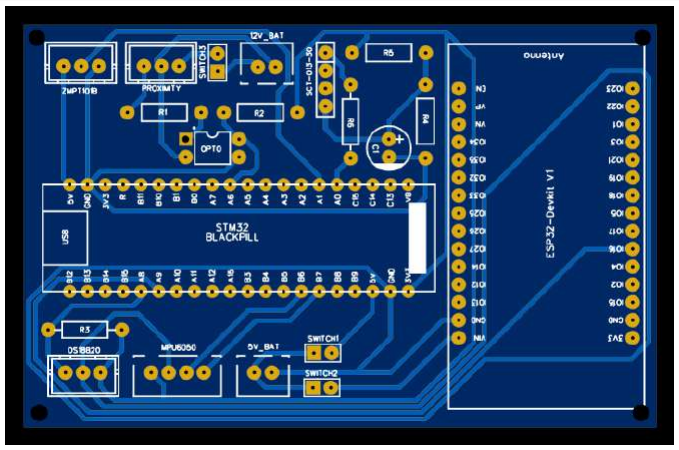
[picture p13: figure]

Figure 4.13: DAQ Device PCB Layout

# CHAPTER 5 SOFTWARE IMPLEMENTATION

## 5.1 Introduction

The Framework acts as the intelligence layer of the entire system. It is the part of the system that collects the data from Data Acquisition Device, processes the collected data, executes the machine learning algorithm, maintains the operational logs and displays the live machine health information using a web dashboard. The software design uses a hybrid edge-cloud model where the sensor data obtained from the industrial machines will be transferred through MQTT protocol and collected by a processor engine made up of Python programming language. The collected data is then pre-processed for cleaning, normalization, outlier removal and feature engineering before being sent to the machine learning model. The predictions generated by the machine learning models are then saved in the Firebase Realtime Database and displayed through the real-time monitor- ing dashboard.

## 5.2 Software Required

Table 5.1 presents the software tools utilized during the development and implementation of the Nirikshak framework.
Table 5.1: Software Requirements
Sr. No. | Software | Purpose
1 | STM32CubeIDE | Firmware development for STM32F103
2 | Arduino IDE | ESP32 programming and debugging
3 | Python 3.10 | Data processing and machine learning
4 | Visual Studio Code | Application development environment
5 | Flask Framework | Backend web server implementation
6 | Flask-SocketIO | Real-time dashboard communication
7 | Firebase Realtime Database | Cloud data storage
8 | Mosquitto MQTT Broker | Message communication between devices
9 | Scikit-Learn | Machine learning model development
10 | Pandas | Data manipulation and preprocessing
11 | NumPy | Numerical computation
12 | Matplotlib | Data visualization and analysis
13 | Git | Version control
14 | GitHub | Project repository management
15 | HTML5, CSS3, JavaScript | Dashboard development

## 5.3 Software Specification

The software specifications used for implementation are presented in Table 5.2. Table 5.2: Software Specifications
Parameter | Specification
Operating System | Windows 11 / Ubuntu 24.04 LTS
Programming Language | Python 3.10
Backend Framework | Flask 2.0+
Real-Time Communication | Flask-SocketIO
MQTT Protocol | MQTT v3.1.1
MQTT Broker | Mosquitto MQTT Broker
Database | Firebase Realtime Database
Frontend Technologies | HTML5, CSS3, JavaScript
Machine Learning Library | Scikit-Learn
Data Processing Library | Pandas
Numerical Computing | NumPy
Version Control | Git
Development Environment | Visual Studio Code
Data Format | JSON, CSV
Communication Security | TLS Encryption
Supported Browser | Chrome, Edge, Firefox

## 5.4 Software Implementation

The software implementation consists of five major modules: MQTT Communication Module, Data Preprocessing Module, Machine Learning Module, Cloud Storage Module, and Dashboard Visualization Module.

### 5.4.1 MQTT Communication Module

The MQTT Communication Module enables wireless communication between the Data Acquisition Device and the Edge Computing Node. The ESP32 Wi-Fi node transmits sensor data for temperature, vibration, voltage, current, and RPM values to the MQTT broker. The Python subscriber listens continuously to the predefined MQTT topic and gets real-time data of machine condition.
The subscriber receives sensor readings, validates the incoming payload and converts it into a structured JSON format for further processing. The data received is simultaneously stored in a local CSV file for backup storage in case of network interruptions.

### 5.4.2 Data Preprocessing Module

Data Preprocessing Module The Data Preprocessing Module prepares the raw sensor data for the machine learning analysis. First, missing values are identified and filled using median imputation techniques from historical operational data. Then the sensor parameters are normalized to a common schema, to ensure all data records are consistent.
Detection of abnormal operating conditions is performed based on rules for detecting outliers. The Temperature, Vibration, Voltage, Current and RPM values are threshold based validation. Once validated, we perform the feature scaling process using the StandardScaler algorithm, to normalize all the sensor values in order to improve the machine learning performance.
The module also calculates the machine operating hours by keeping track of timestamps and cumulative runtime information which is then used for Remaining Useful Life prediction.

### 5.4.3 Machine Learning Module

The Machine Learning Module acts as the brain of the Nirikshak architecture. This module helps in anomaly detection, classification of machine failure, and predicting the Remaining Useful Life (RUL) of industrial machines by using the processed information from sensors. A three-step machine learning process has been proposed for this purpose.

1. Isolation Forest Based Anomaly Detection
The first phase of the predictive maintenance process uses the Isolation Forest technique for the purpose of anomaly detection. Isolation Forest is an unsupervised machine learning algorithm used to detect anomalies by constructing random decision trees.
The algorithm was selected because:
- It does not require labelled fault data.
- It efficiently detects unknown abnormal conditions.
- It provides fast inference suitable for real-time applications.
- It performs well on multidimensional sensor datasets.
The model analyzes incoming sensor readings and generates anomaly scores indicating the likelihood of abnormal machine behaviour.

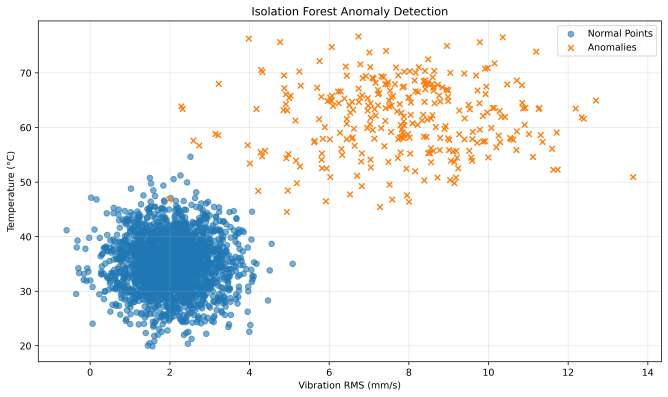
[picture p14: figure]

Figure 5.1: Isolation Forest Anomaly Detection Results

Table 5.3: Isolation Forest Performance
Metric | Value
Accuracy Precision Recall F1 Score | 86.58% 1.0000 0.3735 0.5438

The model achieved perfect precision, indicating that all detected anomalies corresponded to actual abnormal conditions. This minimizes false alarms and improves maintenance decision reliability.

2. Random Forest Based Fault Classification
Following the process of anomaly detection, the sensor data is fed into the Random Forest classifier for performing the diagnosis of faults. The Random Forest classifier is an ensemble machine learning technique based on decision trees.
The classifier identifies the following machine conditions:
- Bearing Fault
- Electrical Fault
- Misalignment
- Rotor Fault
- Overheating
- Unbalance
- Healthy Condition
The algorithm was selected because of its:

- High classification accuracy
- Resistance to overfitting
- Ability to handle nonlinear relationships
- Robustness against noisy industrial data

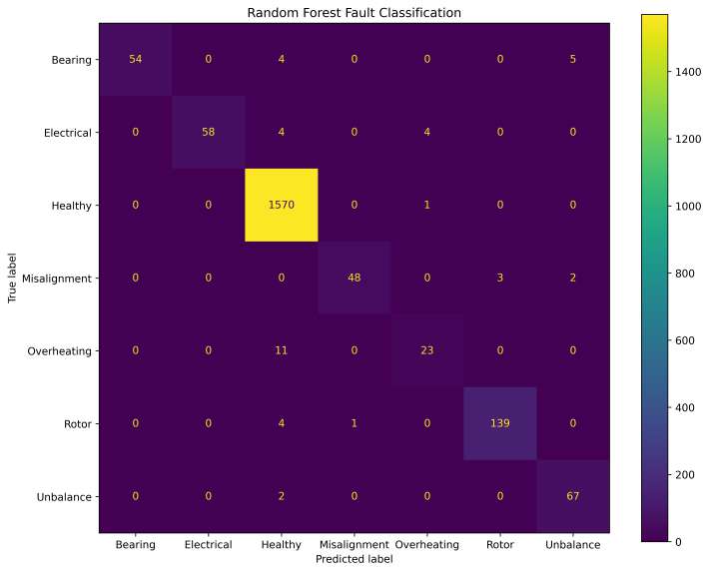
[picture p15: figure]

Figure 5.2: Random Forest Fault Classification Confusion Matrix

Table 5.4: Random Forest Classification Performance
Metric | Value
Accuracy Weighted F1 Score | 97.95% 0.9918

The classifier achieved excellent fault recognition capability with an overall classification accuracy of 97.95%. Most fault categories were correctly identified with minimal class confusion.

3. Random Forest Based Remaining Useful Life Estimation
The final stage of the machine learning pipeline estimates the Remaining Useful Life (RUL) of the machine. A Random Forest Regressor was employed to model degradation trends and predict future machine health.
The regressor estimates the operational duration remaining before maintenance intervention or component replacement becomes necessary. Advantages of the selected regressor include:

- Strong nonlinear modelling capability
- Robustness against sensor noise
- Reduced overfitting
- High prediction accuracy

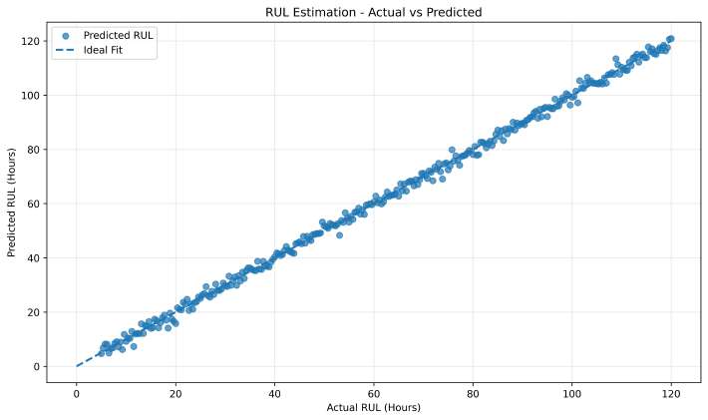
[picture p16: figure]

Figure 5.3: Actual vs Predicted Remaining Useful Life

Table 5.5: RUL Prediction Performance
Metric | Value
RMSE 2 Score R | 4.52 Hours 0.9973

The obtained R

2
score of 0.9973 indicates an excellent correlation between actual and predicted Remaining Useful Life values. The low RMSE value demonstrates accurate lifespan estimation suitable for predictive maintenance applications.
4. Significance of the Proposed Machine Learning Pipeline
The proposed three-stage machine learning pipeline provides a comprehensive predictive maintenance framework by integrating anomaly detection, fault classification, and Remaining Useful Life estimation into a single workflow. The significance of the proposed approach can be summarized as follows:
- Early detection of abnormal machine behaviour.
- Accurate identification of machine fault categories.
- Reliable estimation of machine lifespan.
- Reduction of unplanned downtime.
- Improved maintenance scheduling.

- Enhanced machine reliability and operational efficiency.
- Support for Industry 4.0 based predictive maintenance systems.
The obtained results validate the effectiveness of the Nirikshak framework and demonstrate its suitability for real-time industrial machine monitoring and predictive maintenance applications.

### 5.4.4 Cloud Storage Module

The Cloud Storage Module synchronizes the local processing system with the cloud infrastructure. The sensor readings, anomaly detection results, fault classification outputs and Remaining Useful Life predictions are uploaded to Firebase Realtime Database.
The database is separated into raw sensor data, processed data and machine learning predictions. This segmentation improves data organization and allows the dashboard application to retrieve efficiently.
The cloud storage layer is also accessible remotely, allowing maintenance personnel to monitor machine health from anywhere there is an Internet connection.

### 5.4.5 Dashboard Visualization Module

The Dashboard Visualization Module provides a graphical user interface for realtime monitoring of machine conditions. The dashboard is implemented using HTML5, CSS3 and JavaScript and is connected to the backend through REST APIs and Web-Socket communication.
Dynamic representation of the sensor value readings is done using graphical charts and gauges. Real time data of the parameters of the machines, anomaly status, fault prediction and RUL is displayed on the dashboard without the necessity of refreshing the page. Graphs may also be used for displaying historical data of the sensors, enabling the operators to analyze the machine performance over an extensive period of time. The dashboard acts as the primary interface for decision making for maintenance engineers and plant operators.

## 5.5 Chapter Summary

This chapter described the implemented software of the Nirikshak Industrial IoT-Based Predictive Maintenance Framework. It discussed the software tools, programming environment, system specifications and implementation methodology utilized for implementation of the project. Detailed description regarding operation of the MQTT communications layer, data pretreatment pipeline, machine learning models, cloud database integration and dashboard visualisation was provided. The software architecture being implemented will provide real-time monitoring of machines, detect anomalies, classify faults and predict Remaining Useful Life, providing an intelligent predictive maintenance solution for use in industrial environments.

# CHAPTER 6 TESTING & TROUBLESHOOTING

## 6.1 Introduction

Testing and troubleshooting have been used to validate the performance and reliability of the proposed Nirikshak predictive maintenance framework. Testing is done with the intention of ensuring that the hardware and software elements of the developed framework function as expected and interact with each other without any problem. The developed framework includes several sensors, STM32 and ESP32 microcontrollers, MQTT communication protocol, Firebase cloud storage, machine learning models and web-based dashboard. Hence, testing became necessary to ascertain that each of the sub-components functions properly.
Testing included assessing the accuracy of sensors, effectiveness of communication, synchronization of cloud and the performance of the web-based dashboard among others. Troubleshooting of both hardware and software problems took place throughout the implementation stage. Successful testing indicated that the framework could be used for real time machine condition monitoring and predictive maintenance applications.

## 6.2 Testing Methodology

The testing approach for evaluating both modules individually and the entire system was systematic. First, each sensor was tested individually for the purpose of validating its capacity to capture the corresponding machine parameter. Temperature, vibration, voltage, current, and RPM sensors were validated through the comparison of their output values with the expected values at various operational states of the machine.
Following the process of validating the sensors, communication tests were done between the STM32 microcontroller and ESP32 Wi-Fi module. The collected sensor data was then sent using the MQTT protocol. Consistency and reliability of the transmission of the sensor data were checked. Also, the subscriber application on the edge computing node was tested for successful collection and storing of the sensor data. The machine learning algorithms were tested by collecting and using historical data.
The Isolation Forest algorithm was used to test for anomalies, whereas the Random Forest Classifier algorithm was used to test for faults. The final test carried out was that of end-to-end tests.

## 6.3 Testing Procedure

In order to test the system, all sensors had to be connected to the STM32F103 microcontroller and powered on. The industrial machine was run normally, and the readings from the sensors were monitored throughout the whole process. The data collected was sent to the ESP32 module and then to the MQTT broker.
The data received by the MQTT subscriber application was sent to the Firebase Realtime Database for further processing. The machine learning models were processing the input data and making predictions related to the machine health status. The results of the prediction were then uploaded to the database and shown on the monitoring dashboard.
In order to test the efficiency of the system, abnormal operating conditions like elevated levels of vibrations and temperatures had to be simulated. The input data produced was analyzed by the machine learning models and classified for anomalies and possible faults. The dashboard was monitored to make sure that the results are shown correctly.

## 6.4 Troubleshooting

Some of the problems that arose in the process of implementation and testing include noisy and fluctuating values from the sensors caused by environmental factors and interference from electrical sources. Calibration and filtering through software were used to solve this issue and improve the accuracy of measurements.
Problems related to the loss of WiFi connection resulting in the disconnection of MQTT were solved by ensuring the automatic reconnection capability of the ESP32 software. Delay in data synchronization between the firebase and the dashboard was also experienced while sending the data continuously. Improved synchronization was achieved by optimizing the database updating interval. Inefficient machine learning algorithms were due to the presence of noise from the sensors. Noise reduction and normalization were conducted on the collected data to improve the efficiency of the machine learning models.

## 6.5 Results & Analysis

The developed Nirikshak framework was successfully tested under various operating conditions to evaluate its sensing, communication, cloud integration, dashboard visualization, and machine learning capabilities. The obtained results demonstrate the effectiveness of the proposed Industrial IoT-based predictive maintenance system for real-time machine condition monitoring.

### 6.5.1 Sensor Data Analysis

Parameters such as temperature, vibration, RPM, current, and voltage of machine were continuously monitored while the system was operational. The sensor data captured was successfully transferred through the MQTT network to Firebase Realtime Database.

1. Temperature Analysis
Figure 6.1 shows the temperature variation recorded during machine operation.During normal operating conditions temperature remained stable and increased during simulated overheating scenarios. The observed trend demonstrates the capability of the DS18B20 sensor to monitor thermal behaviour effectively.

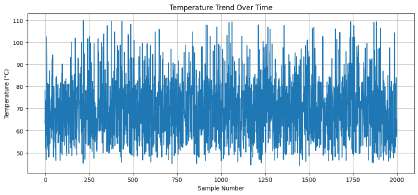
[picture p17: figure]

Figure 6.1: Temperature Trend Analysis

2. Vibration Analysis
Vibration is one of the most important indicators of machine health. Figure 6.2 illustrates the vibration pattern measured using the MPU6050 sensor. Increased vibration amplitudes were observed during abnormal operating conditions, indicating potential imbalance and mechanical faults.

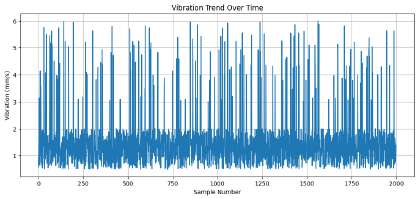
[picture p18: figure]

Figure 6.2: Vibration Trend Analysis

3. RPM Analysis
The rotational speed of the machine was measured using the inductive proximity sensor. Figure 6.3 shows the RPM variation observed during testing. Minor fluctuations were recorded under varying load conditions, while significant deviations were observed during simulated fault scenarios.

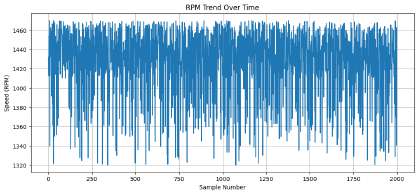
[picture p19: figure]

Figure 6.3: RPM Trend Analysis

4. Current Analysis
Current consumption was monitored using the SCT-013 current sensor. Figure 6.4 presents the current variation during machine operation. Increased current values were observed under overload conditions, indicating higher power consumption and increased mechanical stress.

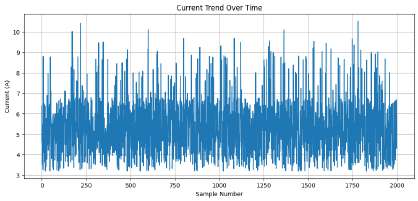
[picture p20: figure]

Figure 6.4: Current Trend Analysis

5. Voltage Analysis
The ZMPT101B voltage sensor continuously monitored the machine supply voltage. Figure 6.5 shows the voltage profile obtained during testing. The voltage remained relatively stable with minor fluctuations, confirming reliable power supply conditions.

Figure 6.5: Voltage Trend Analysis

### 6.5.2 Dashboard Validation

The web-based dashboard successfully displayed real-time machine condition information retrieved from firebase realtime database. Sensor readings, machine health indicators, fault predictions, anomaly status, and remaining useful life estimates were updated dynamically without requiring page refresh.

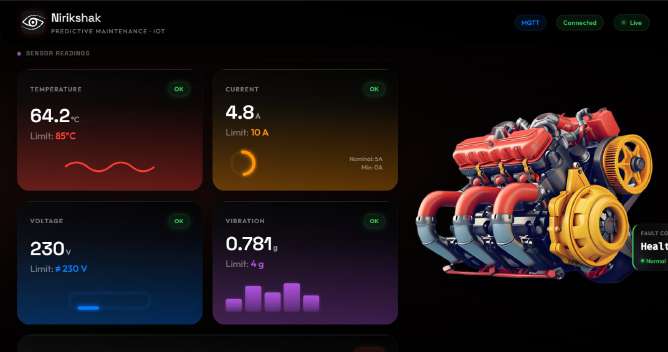
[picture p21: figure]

Figure 6.6: Real-Time Monitoring Dashboard

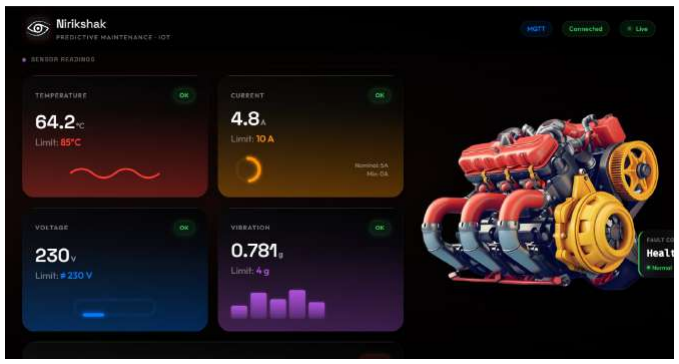
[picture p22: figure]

Figure 6.7: Real-Time Monitoring Dashboard

The dashboard provided a centralized interface for monitoring machine performance and enabled operators to visualize both live and historical machine condition data.

### 6.5.3 Machine Learning Performance Summary

The machine learning models were tested using historical as well as real-time data collected from the sensors. The obtained performance metrics indicate that the proposed predictive maintenance framework effectively analyzes machine health and predicts potential faults. This enables proactive maintenance planning, helping industries reduce downtime, lower maintenance costs, and enhance equipment reliability.

Table 6.1: Performance Evaluation of Machine Learning Models

Machine Learning Model | Application | Performance
Isolation Forest | Anomaly Detection and Out-lier Identification | 86.58% Accuracy
Random Forest Classifier | Fault Detection and Classifi-cation | 97.95% Accuracy
Random Forest Regressor | Remaining Useful Life (RUL) Prediction | 2 = 0.9973 R

The anomaly detection model successfully identified abnormal operating conditions while minimizing false alarms. The Random Forest Classifier accurately distinguished between multiple fault categories and achieved excellent classification performance. The Random Forest Regressor provided highly accurate Remaining Useful Life predictions, demonstrating strong predictive capability.

### 6.5.4 Overall System Performance

Below table summarizes the performance of the complete predictive maintenance framework.
Table 6.2: Overall System Performance Evaluation
Parameter | Result
Temperature Monitoring | Successful
Vibration Monitoring | Successful
RPM Monitoring | Successful
Current Monitoring | Successful
Voltage Monitoring | Successful
MQTT Communication | Successful
Firebase Synchronization | Successful
Dashboard Visualization | Successful
Anomaly Detection Accuracy | 86.58%
Fault Classification Accuracy | 97.95%
RUL Prediction (R 2 Score) | 0.9973

The experimental results validate the effectiveness of the proposed Nirikshak framework. The integrated system successfully performed real-time machine monitoring, anomaly detection, fault classification, cloud synchronization, dashboard visualization, and Remaining Useful Life estimation. The obtained results demonstrate the suitability of the framework for Industrial IoT-based predictive maintenance applications.

# CHAPTER 7 ADVANTAGES & APPLICATIONS

Predictive maintenance has become an essential component of modern industrial systems as it helps organizations minimize unexpected equipment failures and improve operational efficiency. The proposed Nirikshak: An Industrial IoT & Predictive Maintenance Framework integrates Industrial IoT, edge computing, cloud connectivity, and machine learning to provide continuous monitoring and intelligent fault prediction. By analyzing real-time machine parameters, the system enables timely maintenance actions, reduces downtime, and improves equipment reliability. Its low-cost and scalable architecture makes it suitable for both small and large industrial environments.

## 7.1 Advantages

The advantages of the proposed system can be summarized as follows:
fault detection and prediction, enabling timely maintenance before critical failures occur.
1. Reduction in machine downtime through proactive maintenance scheduling and condition-based monitoring.
2. Lower maintenance and operational costs by avoiding unnecessary preventive maintenance and costly breakdowns.
3. Real-time monitoring of machine health using multiple sensors for continuous observation of operating parameters.
4. Remote monitoring through cloud connectivity, allowing operators to access machine status from any location.
5. Improved reliability and equipment performance by continuously tracking machine conditions and degradation patterns.
6. Scalable and flexible system architecture that can be expanded to support multiple machines and industrial environments.
7. Cost-effective implementation using low-cost hardware and open-source technologies, making it suitable for small and medium enterprises.
8. AI-based fault diagnosis and predictive analytics using machine learning algorithms for anomaly detection, fault classification, and Remaining Useful Life (RUL) estimation.
9. Industry 4.0 and Industrial IoT compatibility, supporting smart manufacturing and digital transformation initiatives.

## 7.2 Applications

The proposed system can be employed in a variety of applications such as:

1. Manufacturing industries for monitoring production equipment and reducing downtime.
2. Automotive production facilities for predictive maintenance of assembly line machinery and industrial robots.
3. Power generation plants for monitoring generators, turbines, motors, and auxiliary equipment.
4. Process and chemical industries for ensuring reliable operation of pumps, compressors, and processing units.
5. Smart factories and Industry 4.0 environment for intelligent asset management and automated maintenance planning.
6. HVAC and industrial cooling systems for monitoring temperature, vibration, and equipment performance.
7. Water treatment and pumping stations for continuous supervision of pumps, motors, and control systems.
8. Renewable energy systems such as wind turbines and solar power plants for equipment health assessment.
9. Warehouse automation and material handling systems for monitoring conveyors, motors, and automated machinery.
10. Educational and research laboratories for experimentation, training, and development of Industrial IoT and predictive maintenance technologies.

# CHAPTER 8 CONCLUSION & FUTURE SCOPE

## 8.1 Conclusion

The project Nirikshak: An Industrial IoT Predictive Maintenance Framework has been developed and successfully implemented as an integrated solution for realtime monitoring of machine conditions and predictive maintenance. In the designed framework, Industrial IoT, edge computing, cloud computing, and machine learning are used to monitor important machine parameters and detect any possible faults before failure happens. The developed system provides continuous data collection, analysis, and monitoring. Thus, the unplanned downtime is reduced and the operational efficiency is increased. It is proved that the low-cost predictive maintenance solution for Industry 4.0 can be implemented in industry and SMEs
The major outcomes of the project are summarized as follows:
1. Successfully developed an Industrial IoT-based predictive maintenance framework.
2. Implemented real-time monitoring of temperature, vibration, RPM, voltage, and current parameters.
3. Integrated STM32F103 and ESP32 modules for efficient data acquisition and wireless communication.
4. Established reliable MQTT-based communication for real-time sensor data transmission.
5. Developed an edge computing module for data preprocessing, feature extraction, and analysis.
6. Implemented machine learning models for fault detection and predictive maintenance applications.
7. Enabled anomaly detection and Remaining Useful Life (RUL) estimation for machine health assessment.
8. Integrated Firebase cloud platform for remote data storage, synchronization, and accessibility.
9. Developed a dashboard for real-time visualization, monitoring, and maintenance decision support.
10. Demonstrated a cost-effective, scalable, and Industry 4.0–compatible solution for predictive maintenance.

## 8.2 Future Scope

The proposed system provides a strong foundation for intelligent predictive maintenance; however, several enhancements can be incorporated to further improve its functionality and industrial applicability.

1. Deployment of the framework in large-scale industrial environments for validation under real operating conditions.
2. Integration of additional industrial sensors such as pressure, humidity, acoustic, and thermal imaging sensors for comprehensive equipment monitoring.
3. Development of a dedicated mobile application for remote monitoring, alerts, and maintenance management.
4. Implementation of advanced deep learning models such as CNN, LSTM, Transformer, and hybrid architectures for improved prediction accuracy.
5. Integration of digital twin technology to create virtual representations of industrial assets and enable advanced predictive analytics.
6. Extension of the framework to support multi-machine and multi-site monitoring within a unified platform.
7. Optimization of Edge AI algorithms for faster inference, reduced latency, and lower computational requirements.
8. Integration with enterprise-level systems such as ERP, MES, and SCADA platforms for automated maintenance planning and industrial workflow management.

The future enhancements will further improve the intelligence, scalability, and reliability of the Nirikshak framework, enabling broader adoption of predictive maintenance technologies across modern smart manufacturing environments.

# CHAPTER 9 REFERENCES

[1] A. Theissler, J. Perez-Velazquez, M. Kettelgerdes, and G. Elger, “Predictive maintenance enabled by machine learning: Use cases and challenges in the automotive industry,” Reliability Engineering and System Safety, vol. 215,
p. 107864, 2021.
[2] G. G. Samatas, S. S. Moumgiakmas, and G. A. Papakostas, “Predictive maintenance: Bridging artificial intelligence and iot,” in 2021 IEEE World AI IoT Congress (AIIoT), pp. 413–419, IEEE, 2021.
[3] B. Tasci, A. Omar, and S. Ayvaz, “Remaining useful lifetime prediction for predictive maintenance in manufacturing,” Computers and Industrial Engineering, vol. 184, p. 109566, 2023.
[4] C. Savaglio, P. Mazzei, and G. Fortino, “Edge intelligence for industrial iot: Opportunities and limitations,” Procedia Computer Science, vol. 232, pp. 397– 405, 2024.
[5] S. Elkateb, A. Metwalli, A. Shendy, and A. E. Abu-Elanien, “Machine learning and iot-based predictive maintenance approach for industrial applications,” Alexandria Engineering Journal, vol. 88, pp. 298–309, 2024.
[6] L. Cummins, A. Sommers, S. B. Ramezani, S. Mittal, J. Jabour, M. Seale, and
S. Rahimi, “Explainable predictive maintenance: A survey of current methods, challenges and opportunities,” IEEE Access, vol. 12, pp. 57574–57602, 2024.
[7] F. C. Andriulo, M. Fiore, M. Mongiello, E. Traversa, and V. Zizzo, “Edge computing and cloud computing for internet of things: A review,” Informatics, vol. 11, no. 71, 2024.
[8] V. Artiushenko, S. Lang, C. Lerez, T. Reggelin, and M. Hackert-Oschatzschen, “Resource-efficient edge ai solution for predictive maintenance,” Procedia Computer Science, vol. 232, pp. 348–357, 2024.
[9] M. Hamasha, Q. Albedoor, S. Hamasha, H. Ali, A. Qamar, and F. Barrah, “A comprehensive framework for iot-driven predictive maintenance: Leveraging ai and edge computing for enhanced equipment reliability,” Journal of Applied Engineering Science, vol. 23, no. 3, pp. 471–486, 2025.
[10] R. Rakholia, A. L. Suarez-Cetrulo, M. Singh, and R. S. Carbajo, “Integrating ai and iot for predictive maintenance in industry 4.0 manufacturing environments: A practical approach,” Information, vol. 16, no. 9, p. 737, 2025.

# ANNEXURE A PLAGIARISM REPORT

The Report is Generated by DrillBit Plagiarism Detection Software

Submission Information

Result Information

Author Name | Anisha
Title | Nirikshak: An Industrial IOT and Predictive Maintenance Framework
Paper/Submission ID | 6181354
Submitted by | dipali.dhake@pccoer.in
Submission Date | 2026-06-24 11:14:09
Total Pages, Total Words | 49, 8457
Document type | Project Report
Similarity | 12 %
1 | 10 | 20 | 30 | 40 | 50 | 60 | 70 | 80 | 90

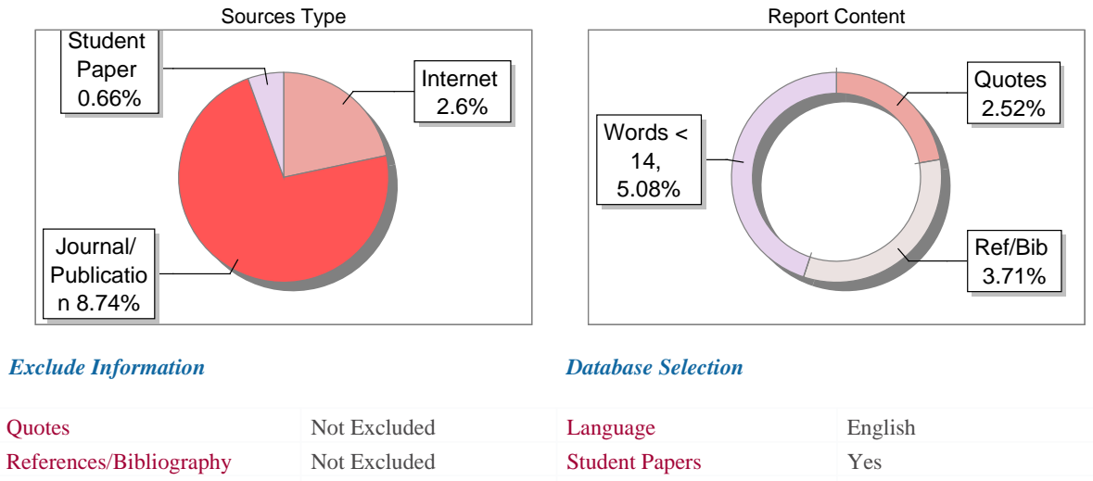
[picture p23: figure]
Exclude Information; Database Selection; Sources Type; Student Paper 0.66%; Journal/ Publicatio n 8.74%; Internet 2.6%; Report Content; Words < 14, 5.08%; Quotes 2.52%; Ref/Bib 3.71%; Quotes; Not Excluded; Language; English; References/Bibliography; Student Papers; Yes

Source: Excluded < 14 Words | Not Excluded | Journals & publishers | Yes
Excluded Source | 0 % | Internet or Web | Yes
Excluded Phrases | Not Excluded | Institution Repository | Yes

A Unique QR Code use to View/Download/Share Pdf File

DrillBit Similarity Report

SIMILARITY % | MATCHED SOURCES | GRADE
LOCATION | MATCHED DOMAIN | % | SOURCE TYPE
12 | 63 | B

A-Satisfactory (0-10%)
B-Upgrade (11-40%)
C-Poor (41-60%)
D-Unacceptable (61-100%)
1 | lcamp.eu | 1 | Publication
2 | jeca.aks.or.id | 1 | Publication
3 | www.ijset.in | 1 | Publication
4 | www.irejournals.com | <1 | Publication
5 | www.ijfmr.com | <1 | Publication

### 6 REPOSITORY - Submitted to Exam section VTU on 2026-02-12 14-57

| 4407174 | <1 | Student Paper
7 | rsisinternational.org | <1 | Publication
8 | www.mdpi.com | <1 | Internet Data
9 | moam.info | <1 | Internet Data
10 | vsip.info | <1 | Internet Data
11 | pdfs.semanticscholar.org | <1 | Publication
12 | Thesis Submitted to Shodhganga Repository | <1 | Publication
13 | Thesis Submitted to Shodhganga Repository | <1 | Publication
14 | ieeexplore.ieee.org | <1 | Publication

### 15 REPOSITORY - Submitted to Malla Reddy Engineering College on

2025-03-28 16-02 3443653

<1 | Student Paper
16 | arxiv.org | <1 | Publication
17 | www.techscience.com | <1 | Internet Data

### 18 IEEE 2017 16th RoEduNet Conference Networking in Education and

| Res, by Awada, Imad Alex M- 2017 | <1 | Publication
19 | ieee-cyber.org | <1 | Publication
20 | public-pages-files-2025.frontiersin.org | <1 | Publication
21 | dokumen.pub | <1 | Internet Data
22 | www.ijraset.com | <1 | Publication
23 | extrica.com | <1 | Internet Data
24 | arxiv.org | <1 | Publication
25 | ijai.iaescore.com | <1 | Publication
26 | rjwave.org | <1 | Publication
27 | www.computersciencejournals.com | <1 | Publication
28 | cdn.unicaf.org | <1 | Publication
29 | Exploring Edge Computing for Multitier Industrial Control by Ma-2020 | <1 | Publication
30 | ijrte.org | <1 | Publication

### 31 Iterating between lessons on concepts and procedures can improve

| mathematics kno by Bethan-2009 | <1 | Publication
32 | www.geeksforgeeks.org | <1 | Internet Data

# ANNEXURE B COPYRIGHT

çek.ki= la- / Certificate No.: LD-20250179380

çfrfyI;fèkdkj çek.ki= | Copyright Certificate
çfrfyI;fèkdkj fu;e dk fu;e 70 | Rule 70 of The Copyright Rules
çfrfyI;fèkdkj jftLVj ls m)j.k | Extracts from the Register of Copyrights
vkosnu la- / Application No.: LD-40629/2025-CO nkf[ky djus dh frfFk/ Date of Filing: 08/10/2025

,rí~okjk ;g çekf.kr fd;k tkrk gS fd çfrfyI;fèkdkj vfèkfu;e] 1957 ds çkoèkkuksa ds vuqlkj] mi;Zqä vkosnu esa çdV fd, x, "NIRIKSHAK: AN INDUSTRIAL IOT AND PREDICTIVE MAINTENANCE FRAMEWORK" uked dk;Z ds fy, çfrfyI;fèkdkj çnku fd;k x;k gSA
This is to certify that a copyright has been registered for the work titled "NIRIKSHAK: AN INDUSTRIAL IOT AND PREDICTIVE MAINTENANCE FRAMEWORK" as disclosed in the below mentioned application in accordance with the provisions of the Copyright Act,1957.

jpf;rk / Authors:
la- / SNO. | uke / Name | irk / Address
1 | SAMARTH RAJESH MAHESHWARI | ROHIT PALM, SOUTH WING, FLAT NO. 404, RAHATANI-411017
2 | ANISHA SANJOG PANSARE | NANDADEEP NIWAS,NEAR CHIMANYA GANAPATI,BRAHMIN ALI,RAJGURUNAGAR-410505
3 | SHRIRAJ SANTOSH DONGARE | SUCHANDRA NIWAS,BEHIND HOTEL KARAM,VIDYANAGAR, SANGAMNER-422605

Lokeh / Owners:
la- / SNO. | uke / Name | irk / Address
1 | SAMARTH RAJESH MAHESHWARI | ROHIT PALM, SOUTH WING, FLAT NO. 404, RAHATANI-411017
2 | ANISHA SANJOG PANSARE | NANDADEEP NIWAS,NEAR CHIMANYA GANAPATI,BRAHMIN ALI,RAJGURUNAGAR-410505

çdk'kd fooj.k /
Publisher Details:
| N.A.

dk;Z dh Hkk"kk /
Language of
the Work:
| English

dk;Z dk fooj.k /
Description
of the Work:

To develop a lowcost, customizable Industrial IoT system that collects realtime machine data, predicts failures using machine learning, and displays key parameters through a userfriendly dashboard. ¼'krZsa@fVIif.k;k¡]
;fn dksbZ gks½ /
(Conditions/
Remarks,
if any):

N.A.

Note: | For Additional details please see next page.

vkj- vks- lh- tkjh gksus dh frfFk /
Date of ROC: 30/12/2025 | Registrar of Copyrights

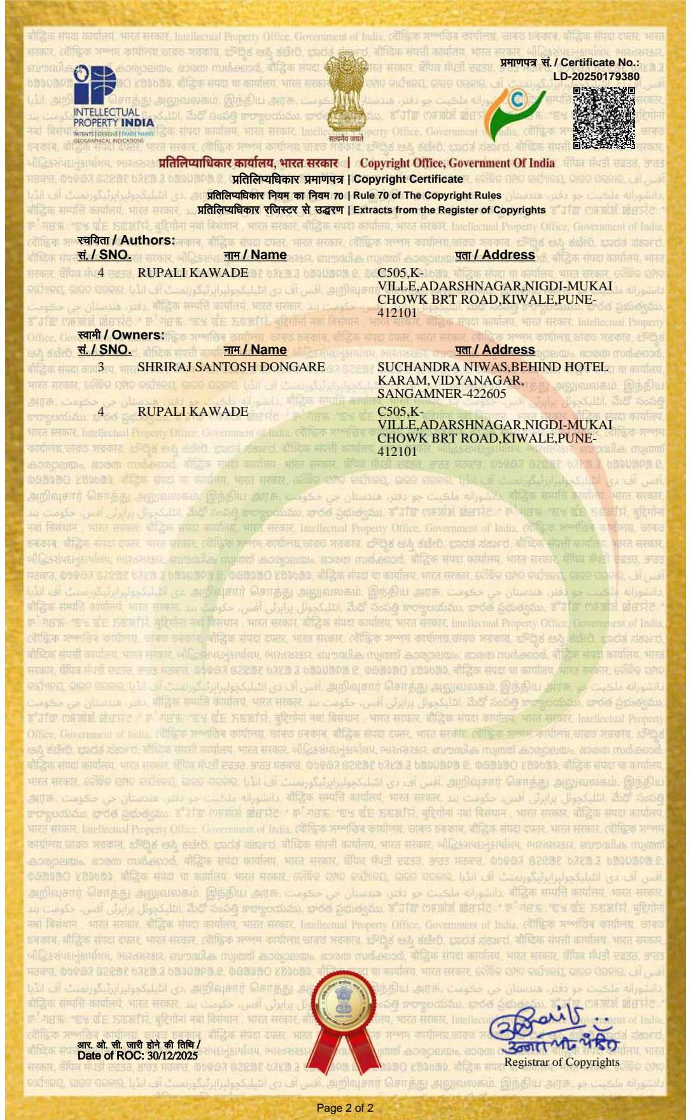
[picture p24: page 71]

çek.ki= la- / Certificate No.: LD-20250179380

çfrfyI;fèkdkj çek.ki= | Copyright Certificate
çfrfyI;fèkdkj fu;e dk fu;e 70 | Rule 70 of The Copyright Rules
çfrfyI;fèkdkj jftLVj ls m)j.k | Extracts from the Register of Copyrights

jpf;rk / Authors:
la- / SNO. | uke / Name | irk / Address
4 | RUPALI KAWADE | C505,K- VILLE,ADARSHNAGAR,NIGDI-MUKAI CHOWK BRT ROAD,KIWALE,PUNE-
| | 412101
Lokeh / Owners:
la- / SNO. | uke / Name | irk / Address
3 | SHRIRAJ SANTOSH DONGARE | SUCHANDRA NIWAS,BEHIND HOTEL KARAM,VIDYANAGAR, SANGAMNER-422605
4 | RUPALI KAWADE | C505,K- VILLE,ADARSHNAGAR,NIGDI-MUKAI CHOWK BRT ROAD,KIWALE,PUNE-
| | 412101

vkj- vks- lh- tkjh gksus dh frfFk /
Date of ROC: 30/12/2025 | Registrar of Copyrights

NIRIKSHAK: AN INDUSTRIAL IOT AND PREDICTIVE MAINTENANCE FRAMEWORK

ABSTRACT:

The fast advancement of the Industrial Internet of Things (IIoT) has allowed industries to transition from reactive and preventive maintenance approaches to predictive maintenance (PdM) systems that guarantee enhanced efficiency, minimized downtime, and streamlined operational expenses. This initiative suggests a predictive maintenance framework based on IIoT, which combines data acquisition (DAQ) systems involving microcontrollers and sensors with wireless communication for monitoring in real-time. Machine metrics like vibration, temperature, and current are continuously gathered and sent to an edge computer that runs a cloud platform for data analysis. Algorithms in machine learning are utilized to examine these parameters, identify anomalies, and forecast possible failures prior to their occurrence. The outcomes are shown on an engaging dashboard that offers visualization, trend analysis, and notifications for maintenance planning. The system guarantees ongoing oversight, immediate decision-making, and anticipatory fault prevention. This system seeks to improve industrial efficiency, reduce unexpected failures, and promote data-centered maintenance approaches in line with Industry 4.0 goals

### 1. Introduction:

The rise of the Industrial Internet of Things (IIoT) has transformed the operational environment of industries, marking the dawn of Industry 4.0. By facilitating connectivity among machines, sensors, controllers, and cloud platforms, IIoT offers immediate insight into industrial assets and processes. Among its numerous applications, predictive maintenance (PdM) has garnered considerable interest as it directly affects the productivity, reliability, and cost efficiency of operations.

Historically, industries depended on corrective maintenance (repairing a machine post-failure) or preventive maintenance (planning repairs at regular intervals irrespective of condition). Corrective maintenance causes expensive downtimes, whereas preventive maintenance can lead to needless servicing and resource wastage. Predictive maintenance utilizes sensor-based data analysis to assess the remaining useful lifespan of machinery, identify initial symptoms of deterioration, and anticipate potential malfunctions. This enables maintenance teams to act solely when needed, achieving a balance between operational efficiency and cost reduction.

The crucial factor for predictive maintenance is the collection and analysis of real-time data. Sensors integrated into equipment constantly track factors like vibration, temperature, current, and pressure. These signals are obtained through microcontroller-driven data acquisition (DAQ) systems and sent wirelessly to cloud or edge platforms. Sophisticated machine learning techniques examine the data to detect unusual patterns, trends, and irregularities. The findings are showcased via interactive dashboards, offering engineers actionable insights and alert notifications.

PdM frameworks based on IIoT have gained significant importance in sectors where downtime results in considerable losses, including manufacturing, energy, and transportation. Through the integration of real-time tracking, wireless connectivity, and AI-powered analysis, PdM minimizes unexpected breakdowns, prolongs the lifespan of equipment, and improves safety in the workplace. Nonetheless, issues like dependable connectivity, precise model training, and compatibility with existing industrial systems need to be tackled for effective implementation.

This initiative seeks to create an affordable IIoT and predictive maintenance system that functions continuously, offering industries immediate machine health data, failure forecasts, and automated decision-making assistance to enhance efficiency and robustness.

### 2. Literature Survey:

Sr. | Authors & Year of Publication | Paper Title | Methodology | Scope for Improvement
1. Soumya Naiya | (2024) | AI-Powered Predictive Maintenance in IoT-Enabled Smart Factories | Discusses AI and IoT integration for real-time predictive maintenance in smart factories; uses ML models like CNN, RNN; shares case studies | Improve data privacy & security; reduce setup costs; address skill shortages; enhance scalable edge computing and federated learning
2. Sasmita Pani, | Omkar Pattnaik, Binod Pattanayak. (2024) | Predictive Maintenance in Industrial IoT Using Machine Learning Approach | Focuses on machine learning methods for predictive maintenance using sensor data; covers data collection, preprocessing, model training, and maintenance recommendation. | Enhance data quality and sensor reliability; manage high costs; improve integration complexity; continuously update models for accuracy
3. Hector, Ida, | Rukmani Panjanathan. (2024) | Predictive Maintenance in Industry 4.0: A Survey of Planning Models and Machine Learning | Reviewed planning models for predictive maintenance. Covered how IoT devices collect data and how ML methods (supervised, unsupervised, deep learning) are used for fault detection, anomaly detection, and remaining useful life prediction. | Models need to be faster and lighter for real-time use.Better integration of IoT with ML/DL.Reduce data needs and cost.Create practical PdM strategies for industries.

4. Nandini Nalawade, | Swati D. Jakkan, Shweta Mangnale, Pradnya Patil. (2020) | Predictive Maintenance for Industrial Equipment using IIoT, AI and ML. | Applies machine learning (Random Forest, LSTM, SVM) and IoT sensors to predict and prevent failures; evaluates models and real-time monitoring | Tackle data quality issues; improve model scalability; reduce complexity; enhance interpretability and industry adaptability
5. Nangia, Shikhil, | Sandhya Makkar, and Rohail Hassan. (2020) | IoT based Predictive Maintenance in Manufacturing Sector | Collected sensor data (temperature, vibration, etc.) from machines; applied ML models (SVM, trees) to predict failures; deployed predictive model in manufacturing. | Scale model across multiple assets; include prescriptive maintenance actions; use big data analytics for scalability
6. Him, Leong Chee, | Yu Yong Poh, and Lee Wah Pheng. (2019) | IoT-based Predictive Maintenance for Smart Manufacturing | Deployed battery-powered IIoT sensor nodes in power plant; used IPv6-based protocols for data collection; monitored latency and battery life; enabled plug & play. | Extend to other manufacturing equipment; add more diverse sensors; automate labeling to improve prediction accuracy

The reviewed studies demonstrate that IoT-enabled predictive maintenance combined with machine learning and deep learning models (SVM, Random Forest, LSTM, CNN, RNN, etc.) significantly improves fault prediction, anomaly detection, and real-time monitoring. Most works focus on sensor-based data collection and algorithmic evaluation, while surveys provide broader insights into planning models and Industry 4.0 applications. Despite these advancements, there remains a gap in developing a holistic and scalable PdM framework that integrates data acquisition, processing, and visualization-which forms the basis of the proposed project.

### 3. Problem statement:

To develop a low-cost, customizable Industrial IoT system that collects real-time machine data, predict failures using machine learning, and displays key parameters through a user-friendly dashboard for efficient predictive maintenance

### 4. Objectives:

The primary objectives of the proposed framework are:
a. To make the DAQ (Data Acquisition) device efficiently collect sensor data in real time.
b. To transmit the collected data in real time to a cloud platform running on a processing device.
c. To implement proper data processing and machine learning techniques for predicting potential failures.
d. To develop a custom dashboard that easily interprets data and sends notifications and alerts for timely action.

### 5. Methodology:

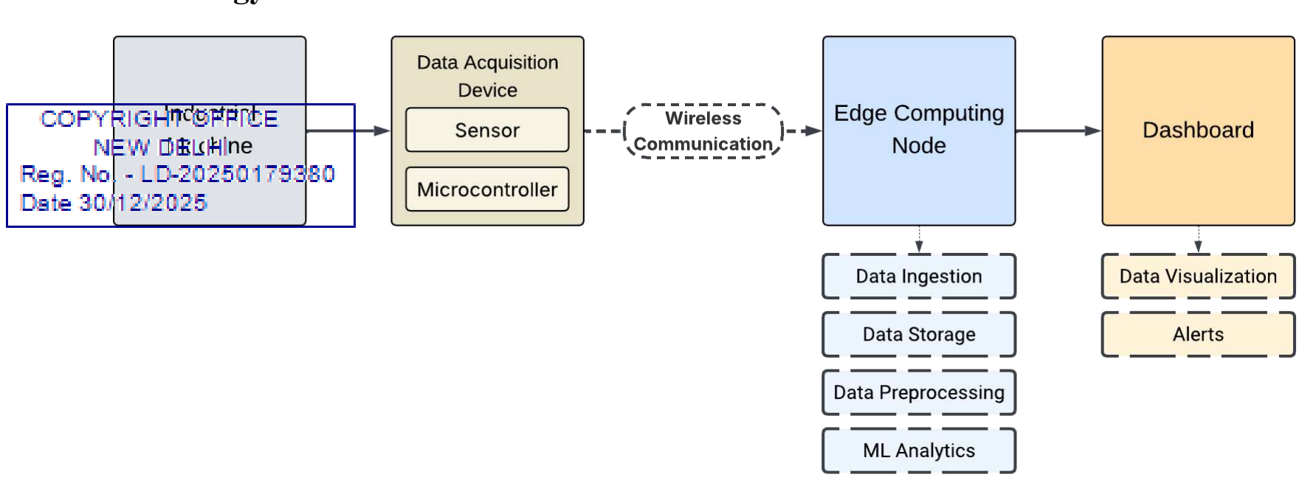
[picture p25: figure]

Figure 1: Block Diagram of Predictive Maintenance Framework

The proposed framework follows a systematic pipeline for real-time predictive maintenance, as illustrated in the block diagram. Each stage is designed to ensure accurate data acquisition, efficient transmission, intelligent processing, and user-friendly visualization.

### 1. Industrial Machine:

The system begins with an industrial machine where various operational parameters (e.g., vibration, temperature, current, pressure) are continuously generated. These parameters serve as input signals for health monitoring.

### 2. Data Acquisition Device:

Sensors are deployed to measure machine parameters in real time. Depending on the application, accelerometers, temperature sensors, or current sensors may be used.
A Microcontroller (such as ESP32/Arduino/STM32) processes the raw sensor signals and converts them into digital form. It acts as the primary Data Acquisition (DAQ) device, responsible for initial signal conditioning and data packaging.

### 3. Wireless Communication:

The processed data is transmitted wirelessly (using Wi-Fi, LoRa, or BLE depending on range and bandwidth requirements) from the DAQ device to the edge computing node. This ensures seamless, low-latency data transfer without manual intervention.

### 4. Edge Computing Node:

At the edge, data undergoes several stages:
- Data Ingestion : Receiving and collecting incoming streams of sensor data.
- Data Storage : Organizing and saving data locally or on a cloud-linked database for historical analysis.
- Data Preprocessing: Filtering noise, normalizing values, and preparing structured datasets suitable for ML analysis.
- ML Analytics: Applying machine learning algorithms to detect anomalies, classify machine states, and predict remaining useful life (RUL). This ensures predictive insights are generated in near real time.

### 5. Dashboard:

The results of analysis are transmitted to a dashboard that provides two major functionalities:
- Data Visualization – Graphs, charts, and trend lines represent machine performance over time, enabling intuitive understanding of machine health.
- Alerts – Notifications are generated automatically when abnormal conditions are detected, supporting proactive maintenance decisions

This methodology ensures continuous, end-to-end monitoring, with seamless integration between sensors, microcontrollers, wireless communication, edge/cloud analytics, and visualization. The system operates in real time, making it scalable for diverse industrial applications

### 6. Conclusion:

This project showcases a predictive maintenance system based on IIoT that combines data gathering, wireless

communication, and smart analysis for real-time monitoring of machine health. The system aids industries in

transitioning from reactive approaches to proactive maintenance by delivering early fault detection and

actionable insights via a tailored dashboard, thus reducing downtime and enhancing reliability.

The solution lowers maintenance expenses while simultaneously improving overall operational effectiveness.

Featuring a flexible and scalable structure, the framework is suitable for various industrial sectors, facilitating

Industry 4.0 efforts and data-oriented asset management.

### 7. Advantages, Disadvantages, and Applications:

a. Advantages:
1. Real-time monitoring: The system enables continuous measurement of key machine parameters such

as vibration, temperature, and current, ensuring that any abnormal deviation is captured instantly. This

allows engineers to intervene at the earliest stage, reducing the risk of catastrophic failures.

2. Reduced downtime: By forecasting potential issues beforehand, companies can arrange maintenance

during scheduled downtime instead of facing unexpected failures. This greatly minimizes idle

machine hours, guaranteeing improved overall equipment effectiveness (OEE).

3. Cost savings: Predictive maintenance reduces unnecessary preventive checks and lowers the

replacement of functioning parts. Eventually, this leads to improved use of spare parts, enhanced

manpower efficiency, and decreased operating costs.

4. Extended equipment lifespan: Continuous monitoring helps maintain machinery within safe

operational limits. Identifying minor issues before they escalate into severe damage extends the

overall lifespan of costly industrial assets.

5. Scalability and flexibility: The framework can be implemented across multiple machines and

industries, as it is based on modular DAQ systems and wireless data transfer. Additional sensors or

algorithms can be integrated as per specific application requirements.

6. Industry 4.0 alignment: The system fits seamlessly into the vision of smart factories and digital

transformation by combining IoT, machine learning, and cloud-edge platforms. It enables industries

to adopt data-driven decision-making and enhance global competitiveness.

b. Disadvantages:
1. Dependence on connectivity: Since the framework relies on wireless transmission, weak signals,

interference, or network outages can lead to delays in data transfer and analysis, reducing the

reliability of real-time predictions.

### 2. Data quality and volume requirements: Machine learning models need large datasets that

accurately represent machine behavior under different operating conditions. Poor-quality or

insufficient data may reduce prediction accuracy and result in false alarms or missed failures.

3. Initial setup complexity: Designing and integrating DAQ hardware, wireless modules, and

dashboard software requires multidisciplinary expertise. For industries without skilled personnel, the

initial deployment may be challenging.

4. Sensor cost and maintenance: High-precision sensors are necessary for reliable data collection.

Deploying multiple sensors across large-scale industrial plants can be expensive, and maintaining

sensor calibration adds additional costs.

5. Cybersecurity risks: Since data is transmitted wirelessly and stored on cloud platforms, the system

may be vulnerable to cyberattacks, unauthorized access, or data breaches if strong security protocols

are not implemented.

c. Applications:
1. Smart factories and manufacturing units: Predictive maintenance can be applied to monitor CNC

machines, robotic arms, conveyor systems, and motors. Early fault detection ensures minimal

production disruption and maximizes throughput.

2. Power plants and energy systems: Turbines, generators, transformers, and pumps are critical assets

in energy plants. Continuous monitoring allows for early identification of overheating, vibration

anomalies, and electrical faults, thereby preventing large-scale outages.
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

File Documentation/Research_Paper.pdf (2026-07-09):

## Nirikshak: An Industrial IoT & Predictive Maintenance Framework

Samarth Maheshwari¹

, Anisha Pansare¹

, Shriraj Dongare¹

and Rupali Kawade²

1Dept. of Electronics and Telecommunication Engineering, Pimpri Chinchwad College Of Engineering Research, Ravet, Pune, Maharashtra, India
2Assistant Professor, Dept. of Electronics and Telecommunication Engineering, Pimpri Chinchwad College of Engineering Research (PCCOER), Ravet, Pune, Maharashtra, India {samarthmaheshwari58, anishapansare1512, shrirajdongare2004, rupali2118}@gmail.com
Keywords: | Industrial IoT, Predictive Maintenance, Edge Computing, Machine Learning, MQTT Communication, Anomaly Detection, Fault Prediction, Remaining Useful Life (RUL), Smart Manufacturing, Real-Time Monitoring
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

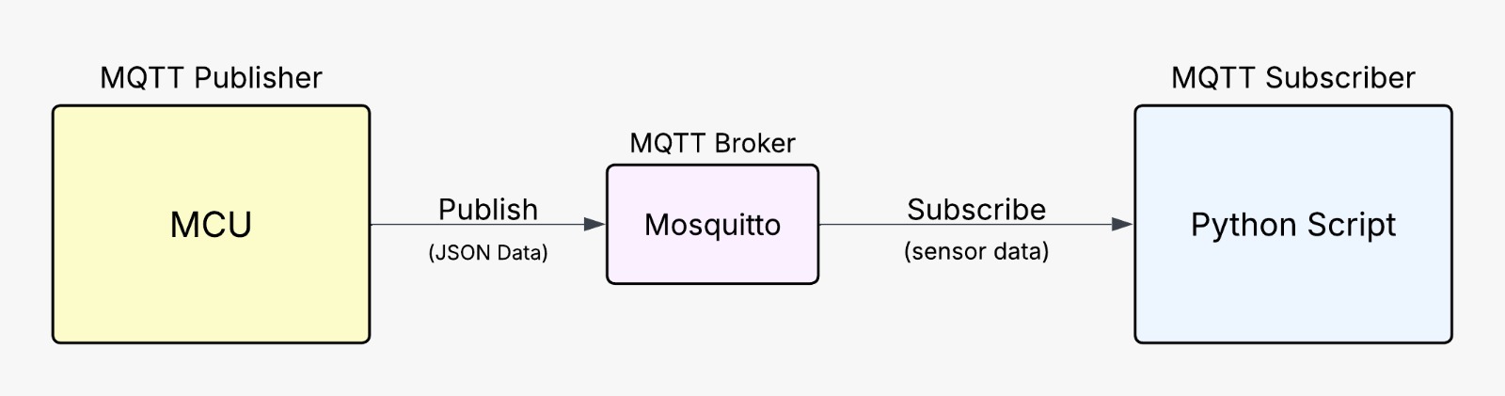
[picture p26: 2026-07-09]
MQTT/mqtt_architecture.jpeg

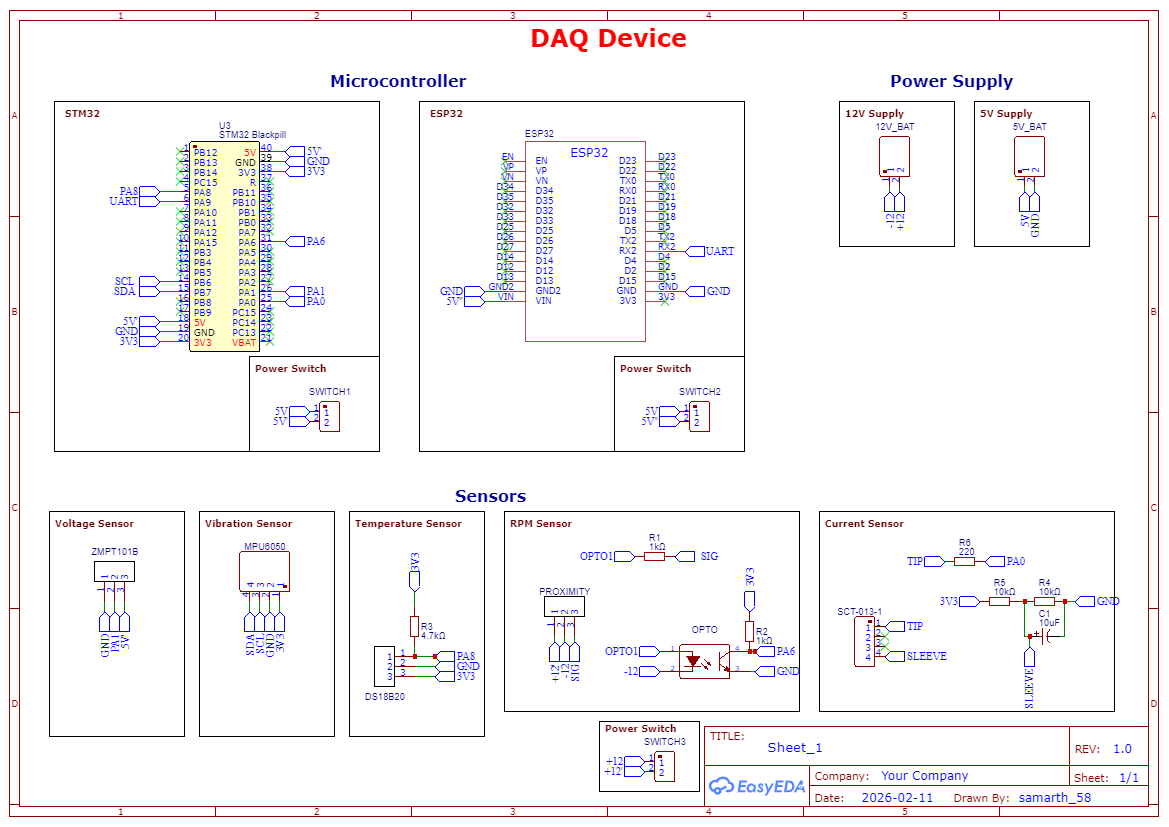
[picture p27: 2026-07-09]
PCB/Schematic/Schematic.png

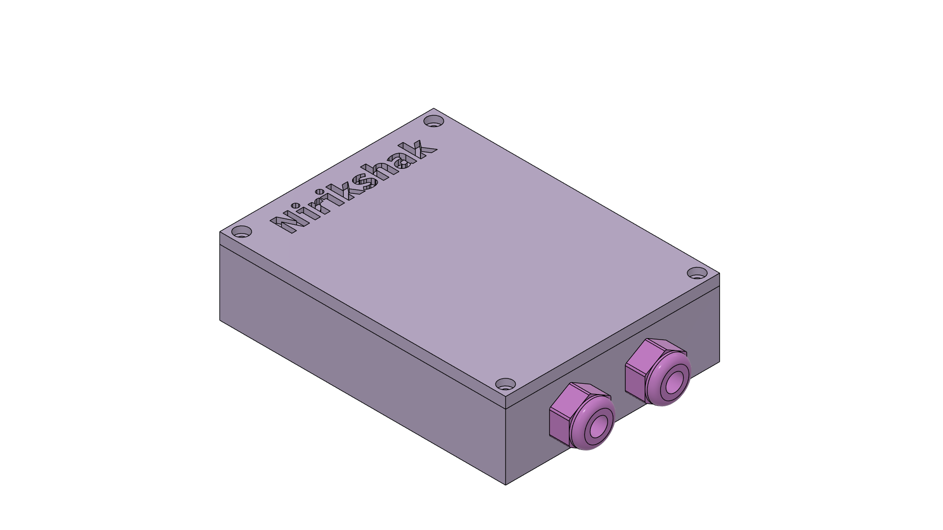
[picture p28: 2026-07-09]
3D_Encloser/Images/DAQ_Final v2.png

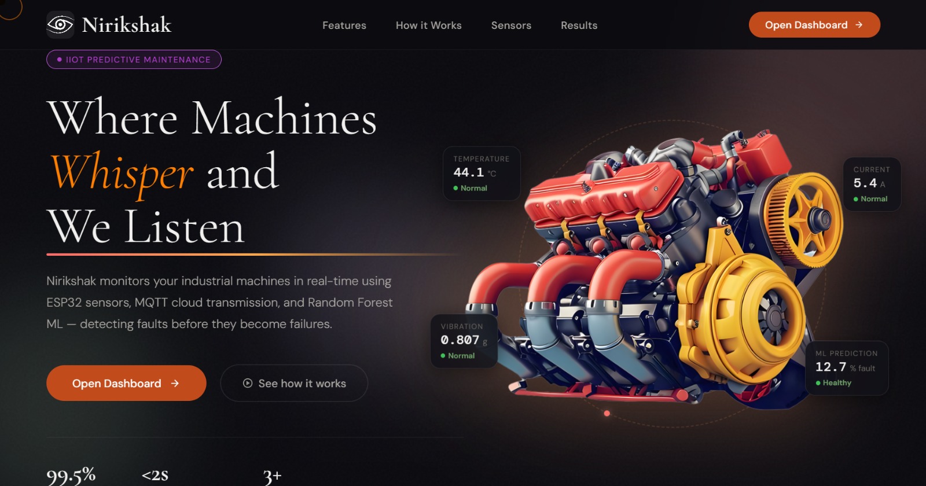
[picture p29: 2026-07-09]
Dashboard/Images/Dashboard1.jpeg

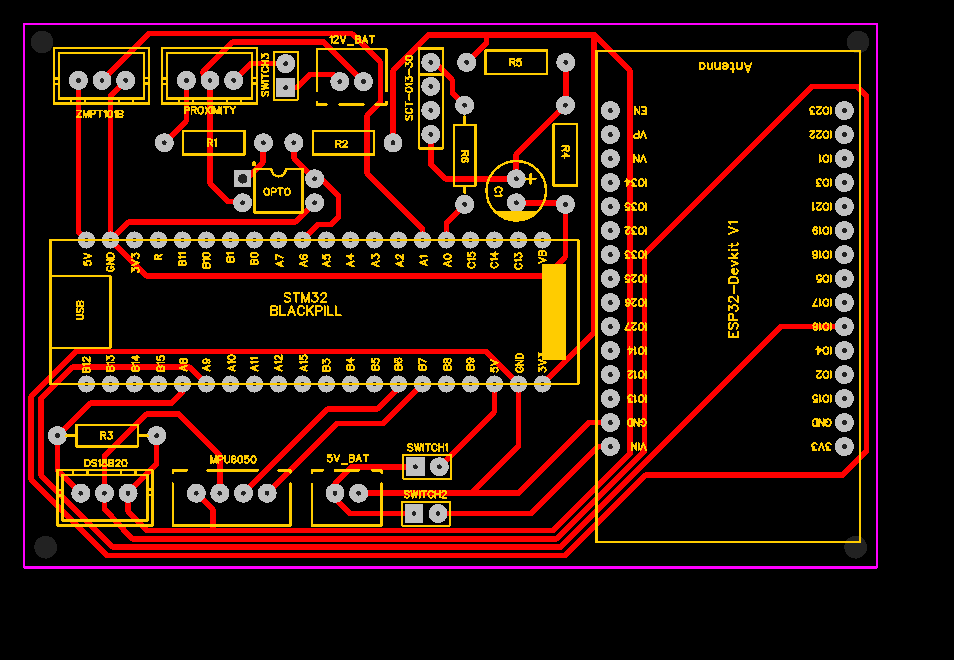
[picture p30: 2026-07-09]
PCB/Layout/Layout.png

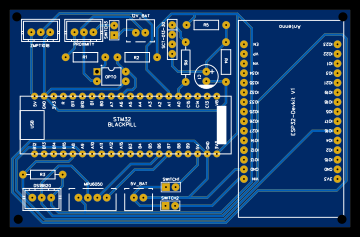
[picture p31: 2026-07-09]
PCB/Layout/2D_View.png

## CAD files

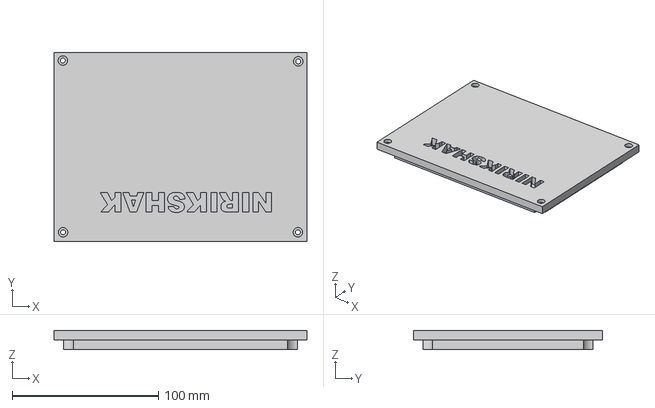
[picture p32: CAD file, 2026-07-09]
3D_Encloser/STEP_File/top_daq.step
173.2 x 129.7 x 13.3 mm

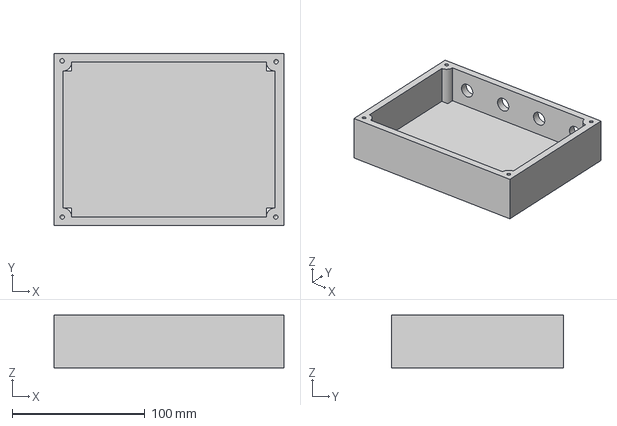
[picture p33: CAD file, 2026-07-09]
3D_Encloser/STEP_File/base_daq.step
173.2 x 129.7 x 39.9 mm

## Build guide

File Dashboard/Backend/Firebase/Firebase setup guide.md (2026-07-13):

# 🔥 Nirikshak — Firebase Realtime Database Setup Guide

## What you get after this guide
- Firebase RTDB storing live sensor data at `/sensors/latest`
- History log at `/sensors/history`
- Dashboard auto-polling Firebase every 2–3 seconds
- ESP32 pushing data directly to Firebase over WiFi

---

## Step 1 — Create a Firebase Project

1. Go to **https://console.firebase.google.com**
2. Click **"Add project"**
3. Name it: `nirikshak` (or anything)
4. Disable Google Analytics (not needed) → **Create project**

---

## Step 2 — Enable Realtime Database

1. In the left sidebar → **Build → Realtime Database**
2. Click **"Create Database"**
3. Choose location: **us-central1** (or closest to you)
4. Start in **test mode** (allows open read/write for 30 days)
5. Click **Enable**

Your database URL will look like:
```
https://nirikshak-default-rtdb.firebaseio.com
```
**Copy this URL — you need it in every file.**

---

## Step 3 — Set Database Rules (Development)

In the Firebase Console → Realtime Database → **Rules** tab,
paste this and click **Publish**:

```json
{
  "rules": {
    ".read": true,
    ".write": true
  }
}
```

> ⚠️ This allows anyone to read/write. Fine for development/college project.
> For production use the rules in `firebase_rules.json`.

---

## Step 4 — Seed Sample Data (Python)

Edit `firebase_setup.py` — find this line and replace with your URL:

```python
FIREBASE_URL = "https://nirikshak-default-rtdb.firebaseio.com"
```

Then run:
```bash
pip install urllib3   # already included in Python standard lib
python firebase_setup.py
```

Expected output:
```
🔥 Connecting to: https://nirikshak-default-rtdb.firebaseio.com
📡 Writing sample data to /sensors/latest ... ✅ Done
📋 Writing sample data to /sensors/history ... ✅ Done (key: -Nxyz...)
⚙️  Writing fault limits to /sensors/config ... ✅ Done

🎉  Firebase setup complete!

Dashboard polling URL:
  https://nirikshak-default-rtdb.firebaseio.com/sensors/latest.json

Sample data written:
  timestamp     : 2025-06-12 14:30:00
  temperature   : 44.2
  current       : 5.1
  voltage       : 219.4
  vibration     : 0.83
  proximity     : 1420
  humidity      : 56.3
  probability   : 7.5
  status        : Normal
  fault         : 0
```

---

## Step 5 — Verify Data in Firebase Console

1. Firebase Console → Realtime Database → **Data** tab
2. You should see:
```
nirikshak-default-rtdb
└── sensors
    ├── latest
    │   ├── temperature: 44.2
    │   ├── current: 5.1
    │   ├── voltage: 219.4
    │   ├── vibration: 0.83
    │   ├── proximity: 1420
    │   ├── humidity: 56.3
    │   ├── probability: 7.5
    │   ├── status: "Normal"
    │   └── fault: 0
    ├── history
    │   └── -Nxyz...
    │       └── (same as latest)
    └── config
        ├── temperature: 65
        ├── current: 10
        ├── voltage: 230
        ├── vibration: 10
        └── proximity: 2000
```

---

## Step 6 — Connect Dashboard to Firebase

1. Open the dashboard in browser: **http://localhost:5000/dashboard**
2. In the **🔥 Firebase** panel, paste your project URL:
   ```
   https://nirikshak-default-rtdb.firebaseio.com
   ```
3. Click **🔥 Connect Firebase**
4. Dashboard header shows **🔥 Firebase** source badge
5. All 5 sensor cards + charts update immediately from cloud data

---

## Step 7A — Simulate Live Data (Python, no ESP32)

Edit `firebase_publisher.py`:
```python
FIREBASE_URL = "https://nirikshak-default-rtdb.firebaseio.com"
```

Run it:
```bash
python firebase_publisher.py
```

Output every 2 seconds:
```
[NORMAL ] Temp=43.2°C  Curr=5.8A  Volt=213.4V  Vib=0.92g  Prox=1380rpm  → Firebase ✅
[NORMAL ] Temp=47.1°C  Curr=4.9A  Volt=218.1V  Vib=1.12g  Prox=1450rpm  → Firebase ✅
[WARNING] Temp=58.4°C  Curr=8.3A  Volt=196.2V  Vib=8.40g  Prox=1720rpm  → Firebase ✅
[FAULT  ] Temp=74.8°C  Curr=12.1A Volt=241.0V  Vib=11.3g  Prox=2250rpm  → Firebase ✅
```

---

## Step 7B — Real ESP32 Publishing

### Required Libraries (Arduino IDE)
Install via **Sketch → Include Library → Manage Libraries**:
| Library | Author |
|---|---|
| Firebase ESP Client | Mobizt |
| ArduinoJson | Benoit Blanchon |
| DHT sensor library | Adafruit |
| Adafruit ADXL345 | Adafruit |

### Credentials to fill in `esp32_firebase.ino`

```cpp
#define WIFI_SSID          "YOUR_WIFI_NAME"
#define WIFI_PASSWORD      "YOUR_WIFI_PASSWORD"
#define FIREBASE_API_KEY   "AIzaSy..."           // Project Settings → Web API Key
#define FIREBASE_DB_URL    "https://nirikshak-default-rtdb.firebaseio.com"
#define FIREBASE_USER_EMAIL    "you@email.com"   // Firebase Auth user
#define FIREBASE_USER_PASSWORD "password"
```

> To create a Firebase Auth user:  
> Firebase Console → Build → Authentication → Sign-in method → Email/Password → Enable  
> Then: Users tab → Add user

### Board Settings (Arduino IDE)
- Board: **ESP32 Dev Module**
- Upload Speed: **921600**
- Port: your COM/tty port

### JSON sent to Firebase every 2 seconds
```json
{
  "timestamp":   "123456s uptime",
  "temperature": 44.2,
  "current":     5.1,
  "voltage":     219.4,
  "vibration":   0.83,
  "proximity":   1420,
  "humidity":    56.3,
  "probability": 7.5,
  "status":      "Normal",
  "fault":       0
}
```

---

## Firebase DB Structure Summary

```
/sensors/latest          ← ESP32 overwrites this every 2s (dashboard polls this)
/sensors/history/{id}    ← ESP32 appends here (full log)
/sensors/config          ← Fault limits reference
```

---

## Troubleshooting

| Problem | Fix |
|---|---|
| `firebase_setup.py` returns 401 | Set rules to test mode (Step 3) |
| Dashboard shows "Firebase Err" | Check URL has no trailing slash, rules are open |
| ESP32 won't connect Firebase | Verify API key and create Auth user (Step 7B) |
| Values show 0 on dashboard | Check JSON keys match exactly (lowercase) |
| CORS error in browser | Add `.json` to end of Firebase URL — RTDB supports browser fetch |

---

## Free Tier Limits (Firebase Spark Plan)

| Resource | Limit |
|---|---|
| Storage | 1 GB |
| Downloads | 10 GB / month |
| Simultaneous connections | 100 |
| **Cost** | **Free** |

At 1 reading every 2 seconds = 43,200 reads/day = well within free limits.

---

*Nirikshak — Predictive Maintenance · PCCOE 2025–26*

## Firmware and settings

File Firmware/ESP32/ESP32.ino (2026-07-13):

#include <WiFi.h>
#include <PubSubClient.h>

/* ================= WiFi Credentials ================= */
const char* ssid     = "ssid_name";
const char* password = "ssid_password";

/* ================= MQTT Config ================= */
const char* mqtt_server = "laptop/pc_id";
const int   mqtt_port   = 1883;
const char* mqtt_topic  = "sensor/data";

WiFiClient espClient;
PubSubClient client(espClient);

/* ================= Sensor Data ================= */
String temperature = "";
String currentVal  = "";
String voltage     = "";
String rpm         = "";
String vibration   = "";

/* ================= MQTT Reconnect ================= */
void reconnectMQTT() {
  while (!client.connected()) {
    Serial.print("Connecting to MQTT...");

    if (client.connect("ESP32_PDM")) {
      Serial.println(" Connected!");
    } else {
      Serial.print(" Failed, rc=");
      Serial.println(client.state());
      delay(2000);
    }
  }
}

/* ================= Parse UART Data ================= */
void parseData(String data) {

  int t  = data.indexOf("TEMP:");
  int c  = data.indexOf("CUR:");
  int v  = data.indexOf("VOLT:");
  int r  = data.indexOf("RPM:");
  int vb = data.indexOf("VIB:");

  if (t  != -1) temperature = data.substring(t + 5, data.indexOf(",", t));
  if (c  != -1) currentVal  = data.substring(c + 4, data.indexOf(",", c));
  if (v  != -1) voltage     = data.substring(v + 5, data.indexOf(",", v));
  if (r  != -1) rpm         = data.substring(r + 4, data.indexOf(",", r));
  if (vb != -1) vibration   = data.substring(vb + 4);
}

/* ================= Setup ================= */
unsigned long lastPublish = 0;

void setup() {

  Serial.begin(115200);

  // STM32 UART
  Serial2.begin(115200, SERIAL_8N1, 16, 17);

  /* WiFi */
  WiFi.begin(ssid, password);

  Serial.print("Connecting WiFi");

  while (WiFi.status() != WL_CONNECTED) {
    delay(500);
    Serial.print(".");
  }

  Serial.println("\nWiFi Connected");
  Serial.print("ESP32 IP: ");
  Serial.println(WiFi.localIP());

  /* MQTT */
  client.setServer(mqtt_server, mqtt_port);
}

/* ================= Loop ================= */
void loop() {

  if (!client.connected()) {
    reconnectMQTT();
  }

  client.loop();

  /* Receive STM32 Data */
  if (Serial2.available()) {

    String incoming = Serial2.readStringUntil('\n');
    incoming.trim();

    Serial.println("UART Received:");
    Serial.println(incoming);

    parseData(incoming);
  }

  /* Publish every second */
  if (millis() - lastPublish >= 1000) {

    lastPublish = millis();

    if (temperature != "--") {

      char payload[200];

      snprintf(payload, sizeof(payload),
               "{\"temperature\": %s, "
               "\"current\": %s, "
               "\"voltage\": %s, "
               "\"rpm\": %s, "
               "\"vibration\": %s}",
               temperature.c_str(),
               currentVal.c_str(),
               voltage.c_str(),
               rpm.c_str(),
               vibration.c_str());

      client.publish(mqtt_topic, payload);

      Serial.println("MQTT Published:");
      Serial.println(payload);
    }
  }
}

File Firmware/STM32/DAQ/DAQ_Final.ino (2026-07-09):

#include <Wire.h>
#include <I2Cdev.h>
#include <MPU6050.h>

#include <OneWire.h>
#include <DallasTemperature.h>

#include "sensor_manager.h"

SensorData_t sensorData;

void setup()
{
    // UART to ESP32 (USART1 → PA9 TX, PA10 RX)
    Serial1.begin(115200);

    // Initialize all sensors
    SensorManager_Init();

    Serial1.println("DAQ_START");
}

void loop()
{
    SensorManager_ReadAll(&sensorData);

    // ===== FORMAT EXPECTED BY ESP32 =====
    Serial1.print("TEMP:");
    Serial1.print(sensorData.temperature, 1);
    Serial1.print(",");

    Serial1.print("CUR:");
    Serial1.print(sensorData.current, 2);
    Serial1.print(",");

    Serial1.print("VOLT:");
    Serial1.print(sensorData.voltage, 1);
    Serial1.print(",");

    Serial1.print("RPM:");
    Serial1.print(sensorData.rpm);
    Serial1.print(",");

    Serial1.print("VIB:");
    Serial1.println(sensorData.vibration, 4);

    delay(1000);
}

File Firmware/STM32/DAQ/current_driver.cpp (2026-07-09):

#include "current_driver.h"
#include <math.h>

// ===== CONFIG =====
static uint8_t _adcPin;

static const float ADC_REF = 3.3;
static const int ADC_MAX = 4095;
static const int SAMPLES = 2000;
static const float NOISE_THRESHOLD = 0.01;

// ===== CALIBRATION =====
static float calibrationFactor = 29.4;
static float offset = 1.65;

void Current_Init(uint8_t adcPin)
{
    _adcPin = adcPin;

    analogReadResolution(12); 
}

void Current_SetCalibration(float factor, float offs)
{
    calibrationFactor = factor;
    offset = offs;
}

float Current_ReadRMS(void)
{
    float sumSq = 0;

    for (int i = 0; i < SAMPLES; i++)
    {
        int raw = analogRead(_adcPin);
        float voltage = (raw * ADC_REF) / ADC_MAX;
        float ac = voltage - offset;
        sumSq += ac * ac;
        delayMicroseconds(200);
    }

    float rmsV = sqrt(sumSq / SAMPLES);

    if (rmsV < NOISE_THRESHOLD)
        return 0.0;

    return rmsV * calibrationFactor;
}
